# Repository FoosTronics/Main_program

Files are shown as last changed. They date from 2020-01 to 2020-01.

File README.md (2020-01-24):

# pageres

# FoosTronics
> De AI gestuurde voetbaltafel.

FoosTronics is een NLE minor project van de Hogeschool Utrecht (HU), waarbij de keeper van een fysieke voetbaltafel wordt bestuurd doormiddel van een AI. 

## Motivatie
Het project is gekozen om meer te leren over: AI, beeldherkenning, mechanica en hardware. 

## Doxygen
De Doxygen documenten zijn te vinden onder: Extra/Doxygen documentatie	

## Packages
| Package | Versie | 
| --- | --- |
| OpenCV (cv2)  | 4.1.1 | 
| TensorFlow | 1.14.1-dev20190625  | 
| numpy | 1.16.5 | 
| matplotlib | 3.1.1 | 
| Box2D | 2.3.2 | 
| smbus | 0.3.0 | 
| usb1 | 1.7.1 | 
| imutils | 0.5.3 | 
| numba | 0.45.1 | 
| pygame | 1.9.6 | 

## Hardware componenten
| Component | Versie | 
| --- | --- |
| Jetson | Nano | 
| RPI Cam | V2.1 |
| Stappenmotor 2.3 inch | KH56JM2 | 
| Stappenmotor 1.7 inch | 17PU-H502 |
| Motordriver | Arcus Technology ACE-SDE  |
| Gyroscoop | MPU6050 |

> In de handleiding staan de installatie- en gebruiksinstructies. Hierin is onder andere de opbouw van het frame te vinden onder Extra/Handleiding FoosTronics - V1.1.pdf.

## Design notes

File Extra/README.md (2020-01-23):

# FoosTronics Extra
> Extra bestanden die benodigd zijn om de FoosTronics tafel te realiseren.

## Mappen
**3D-Modellen** 
  STL files van de 3D-prints.
  
**3D-Tekeningen** 
  SLDPRT (SolidWorks) en SKP (SketchUp) files die zijn gebruikt voor het project.

**Promo**
  Promo bestanden zoals afbeeldingen en logo.
  
## Files
Handleiding voor het installeren van de FoosTronics tafel - *Handleiding FoosTronics - V1.1.pdf* 
  
## Constructie
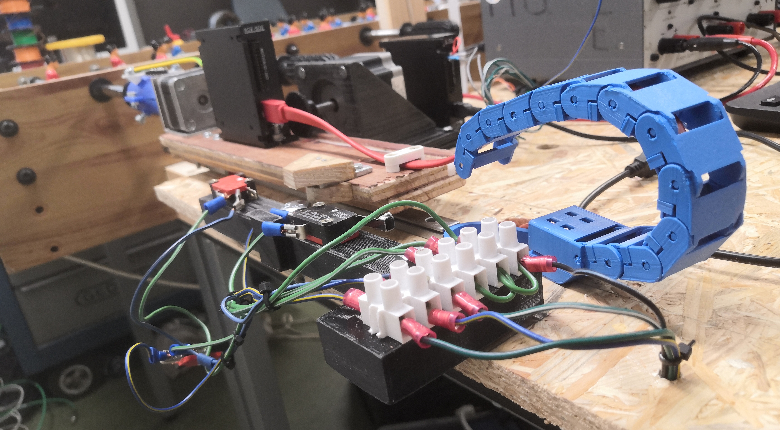
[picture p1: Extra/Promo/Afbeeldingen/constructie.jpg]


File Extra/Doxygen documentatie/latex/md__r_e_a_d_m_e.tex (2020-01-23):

C\+:\textbackslash{}\+Users\textbackslash{}kelvi\textbackslash{}\+Documents\textbackslash{}\+HU\textbackslash{}\+Next Level Engineering\textbackslash{}\+Software\textbackslash{}\+Main\+\_\+\+Foos\+Tronics\textbackslash{}\+Jetson$>$python -\/m doxypypy.\+doxypypy -\/a -\/c \char`\"{}\+C\+:/\+Users/kelvi/\+Documents/\+H\+U/\+Next Level Engineering/\+Software/\+Main\+\_\+\+Foos\+Tronics/\+Jetson/\+R\+E\+A\+D\+M\+E.\+md\char`\"{} \hypertarget{md__r_e_a_d_m_e_autotoc_md0}{}\doxysection{Foos\+Tronics}\label{md__r_e_a_d_m_e_autotoc_md0}

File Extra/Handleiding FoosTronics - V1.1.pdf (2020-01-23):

# FoosTronics

### Handleiding

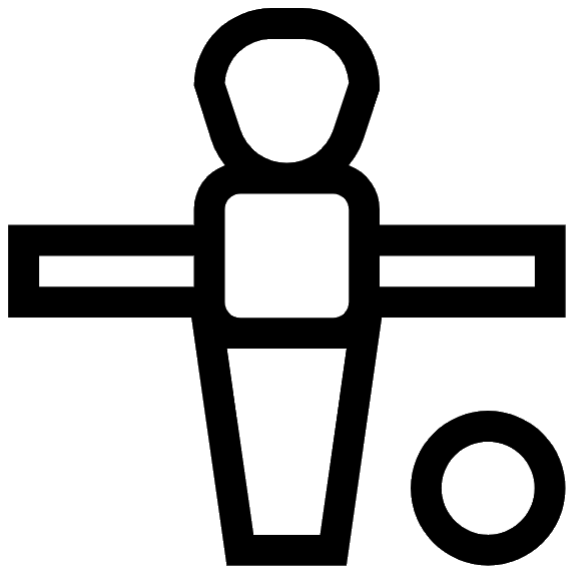
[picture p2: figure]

Namen: | Daniël Boon | 1703713
| Kelvin Sweere | 1698097
| Chileam Bohnen | 1630416
| Sipke Vellinga | 1706887
Minor: | Next Level Engineering
Cursuscode: | TIED-MNLE-18
Docent(en): | Franc van der Bent
| Abdelhak El Jazouli
| Petra Verbeek
| Michiel Scager
15-1-2019 | Versie 1.1

Pagina 2 van 51

### Revisie index

Versie | Datum | Beschrijving
V0.0 | 20-12-2019 | Opzet handleiding
V0.1 | 03-01-2020 | Inhoud toegevoegd aan de lay-out
V0.2 | 08-01-2020 | Inhoud compleet
V0.3 | 09-01-2020 | Commentaren projectgroep verbeterd
V0.4 | 09-01-2020 | Lay-out aangepast
V0.5 | 10-01-2020 | Feedback peer verwerkt
V1.0 | 10-01-2020 | Releasedatum handleiding
V1.1 | 15-01-2020 | Opmerkingen toegevoegd en verwijderd

Pagina 3 van 51

## Inhoudsopgave

Pagina 4 van 51

## 1. Inleiding

Om het project “FoosTronics”, dat is uitgevoerd tijdens de Minor Next Level Engineering van de opleiding Elektrotechniek, beter over te kunnen dragen aan andere docenten en studenten is er gekozen om een handleiding te schrijven.

Voor het gebruik van dit product worden minimaal 3e
jaars elektrotechnici verwacht. Het doel van het product is vooral om deze tijdens open dagen te laten zien.

Voor het opzetten van de handleiding is onder ander gebruik gemaakt van de lay-out van Vermeulen (Vermeulen, 2019) en voor het schriftelijke deel is gebruik gemaakt van informatie van Bloom (Bloom, 2019).

Met behulp van deze handleiding kan de FoosTronics tafelvoetbaltafel worden geïnstalleerd en in gebruik worden genomen. Er wordt vanuit gegaan dat de tafelvoetbaltafel vanaf een volledig gedemonteerd product in elkaar gezet moet worden.

In de volgende hoofdstukken zal eerst het product worden beschreven aan de hand van de kenmerken en specificaties. Vervolgens zal er worden ingegaan op welke veiligheidsvoorschriften van belang zijn om ongelukken te vermijden. Met deze kennis in het achterhoofd worden de gebruiksinstructies voorgeschreven gevolgd door de installatie instructies.
Verder zal er een troubleshooting sectie te vinden zijn waar de meeste voor te komen problemen zijn opgesomd samen met een beschrijving hoe deze zijn op te lossen. Dit wordt gevolgd door een aantal onderhoudstips om het product in een zo goed mogelijke staat te houden. De gehele handleiding wordt afgesloten met contactgegevens mochten er nog onduidelijkheden ontstaan na het lezen van deze handleiding (gaan we niet vanuit natuurlijk).

Pagina 5 van 51

## 2. Product: FoosTronics

In dit hoofdstuk worden de kenmerken en specificaties van het product beschreven.

## 2.1 Kenmerken

Het product kan het volgende:
- Met behulp van beeldherkenning wordt de tafelvoetbal bal gedetecteerd en gevolgd.
- De keeper kan met behulp van de richting van de bal bewegen naar een berekende positie.
- De keeper kan met behulp van beeldherkenning en artificiële intelligentie interactie hebben met de bal.

## 2.2 Specificaties

Jetson Nano
- Product model: NVIDIA JETSON NANO DEVELOPER KIT
- Voedingspanning: 5V
- Voedingsstroom: 4A
- Vermogen: 5-25 watt
- Maten: 69.6 mm x 45 mm
- Aansluitingen:
- Monitor: HDMI 2.0 en Displayport 1.4
- Ethernet: RJ45, M.2 Key E
- Camera connector: 1x MIPI CSI-2 DPHY lanes
- Overig: GPIO, I²C, I²
S, SPI, UART

Raspberry Pi camera
- Product Model: V2.1
- Compatibel met Raspberry Pi 4 en Jetson Nano
- Maten: 25mm x 23mm
- Aansluiting:
- Camera connector: CSI-2

Stappenmotor 2,3 inch
- Product model: KH56KM2
- Klemspanning: 12V
- Normaal stroom: 1A
- Aansluiting:
- 6-pins JST A en B-fasen

Stappenmotor 1,7 inch
- Product model: 17PU-H502
- Klemspanning: 12V
- Normaal stroom: 0,8A
- Aansluiting:
- 6-pins JST A en B-fasen

Pagina 6 van 51

Motordriver
- Arcus Technology ACE-SDE Single axis controller plus microstep driver
- Voedingsspanning: 12V – 48V
- Voedingsstroom: 3A
- Aansluitingen:
- 2-pins klemblokken voeding
- 4-pins klemblokken A en B-fasen
- USB-mini voor aansturing
- 28-pins 2mm dubbele rij IO-connector voor schakelaars

Gyroscoop
- Product model: MPU6050
- Voedingsspanning: 3.3V
- Voedingsstroom: 3.6mA
- Aansluiting:
- I

2C
- SPI

Pagina 7 van 51

## 3. BELANGRIJKE VEILIGHEIDSWAARSCHUWINGEN

## Lees dit hoofdstuk rustig door om ongelukken te voorkomen voordat u

gebruik maakt van het product.

### Productnaam: FoosTronics tafelvoetbaltafel

- Dit product maakt gebruik van spanningen en stromen die schadelijk zijn voor het menselijk lichaam, raak daarom geen blote delen aan en laat werkzaamheden aan elektronische componenten alleen over aan deskundigen.
- Controleer vooraf of alle zichtbare delen onbeschadigd zijn alvorens gebruik te maken van het product. In geval van schade, laat dit eerst repareren.
- Componenten kunnen gevoelig zijn voor statische elektriciteit. Maak bij contact daarom altijd gebruik van antistatische maatregelingen, zoals een polsband.
- Zorg ervoor dat het product in een schone en droge omgeving staat.
- Zorg ervoor dat de omgevingstemperatuur te allen tijde tussen de 15°C en 25°C is.
- Het product mag niet in direct zonlicht worden geplaatst.
- Vloeistoffen kunnen grote schade aanrichten, zorg daarom dat deze op veilige afstand van het product staan.
- Houd handen, haar, kleding en andere voorwerpen buiten bereik van tandwielen en andere bewegende delen om persoonlijk letsel te voorkomen.
- Wanneer het product niet gebruikt wordt, schakel dan eerst de Jetson Nano uit met behulp van de aan/uit knop en haal daarna de stekker uit het stopcontact.
- In geval van brand gebruik bij voorkeur een schuimbrandblusser.
- Dit product is niet geschikt voor kinderen onder de 12 jaar.
- Schakel het apparaat altijd uit alvorens er gereinigd wordt.

### Gebruik van dit product is volledig op eigen risico en er is dan ook geen enkele

aansprakelijkheid op de ontwikkelaars of andere betrokkenen.

Pagina 8 van 51

## 4. Installatie instructies

In dit hoofdstuk staat beschreven hoe de FoosTronics tafelvoetbaltafel wordt opgebouwd en geïnstalleerd. Dit hoofdstuk is voor gebruikers en doorontwikkelaars die het besturingssysteem willen installeren en de tafelvoetbaltafel willen opbouwen.

Per onderdeel van FoosTronics zijn de benodigde materialen en gereedschappen beschreven. Met behulp van een stappenplan is beschreven hoe de onderdelen gebouwd, gemonteerd en geïnstalleerd kunnen worden. Voordat wordt begonnen met de uitvoering van de installatie wordt geadviseerd eerst de stappen door te nemen.

De volgorde voor het opbouwen van FoosTronics begint bij het aansluiten en installeren van de Jetson Nano. Dit is gedaan, omdat het installeren van het besturingssysteem en benodigde Python modules veel tijd kosten. In de tussentijd van het installeren kunnen de andere onderdelen worden opgebouwd en gemonteerd.

De materialen die gebruikt worden bestaan uit halffabricaten. De technische tekeningen van deze halffabricaten staan op GitHub: https://github.com/CookieLover22/FoosTronics/tree/master/3D-prints. Wanneer blijkt dat er tijdens het uitvoeren van de installatie instructies een onderdeel mist vul deze dan a.u.b. aan, verhoog het versienummer en vermeld de wijziging in de revisie index.

Kort overzicht van de paragrafen
1. Aansluiten Jetson Nano t.b.v. installatie
2. Installeren Jetson Nano
3. Opbouwen frame
4. Monteren van de laterale mechanica
5. Monteren van de axiale mechanica
6. Monteren van Jetson Nano
7. Monteren van camera

Pagina 9 van 51

## 4.1 Aansluiten Jetson Nano t.b.v. installatie

In deze paragraaf wordt de Jetson Nano aangesloten zodat de benodigde installaties voor de Jetson Nano uitgevoerd kunnen worden. In Tabel 1 is een lijst weergegeven van alle benodigde materialen.

Tabel 1: Materialen voor het aansluiten van de Jetson Nano

Materialenlijst
Aantal | Materiaal | Afmetingen | Voorbeeld (Noun Project Inc., 2020)
1 | Jetson Nano | n.v.t
1 | 5V adapter (4A geadviseerd) | Barrel connector OD 5,5mm ID 2,1mm
1 | 5V actieve koeling met 2-pinsconnector | 40mm * 40mm * 10mm
1 | Monitor met HDMI of Display port | n.v.t
1 | HDMI of Display port kabel (aansluitbaar op de monitor) | Minimaal lengte van 1 meter
1 | M.2 wifi/bluetooth module | n.v.t.
1 | (optioneel) UTP-kabel voor internetverbinding | n.v.t.
1 | USB-keyboard | n.v.t
1 | USB-muis | n.v.t
2 | Drukknoppen
1 | Jumper cap | 2.54mm pitch

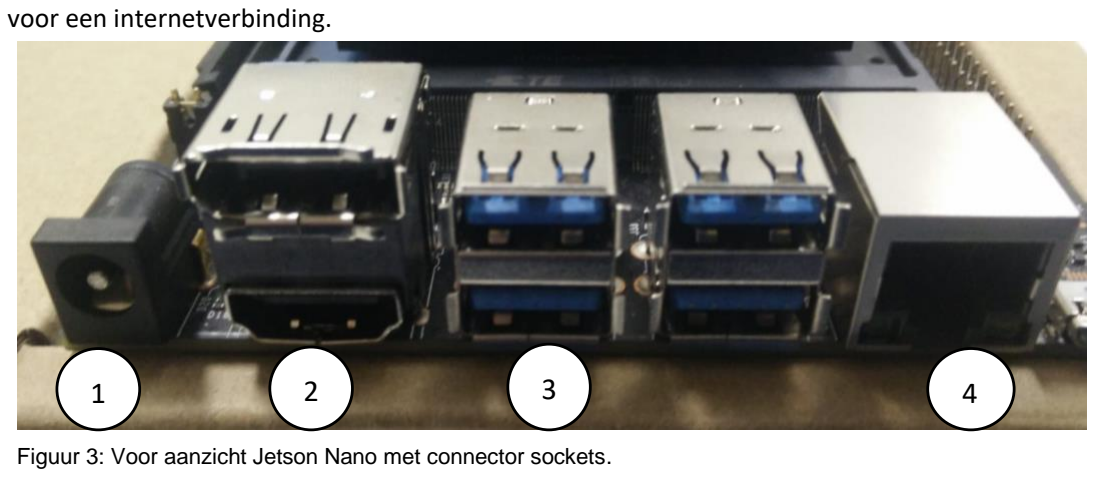
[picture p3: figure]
voor een internetverbinding.

Pagina 10 van 51

### 4.1.1 Stappenplan

1. Om een M.2 wifimodule te gebruiken, dient de Jetson Nano module van het moederbord te worden ontkoppeld. Als er geen M.2 wifimodule wordt gebruikt, ga naar stap 4.
2. In het onderstaande voorbeeld, zie Figuur 1, wordt een M.2 wifi/bluetooth module geplaatst.

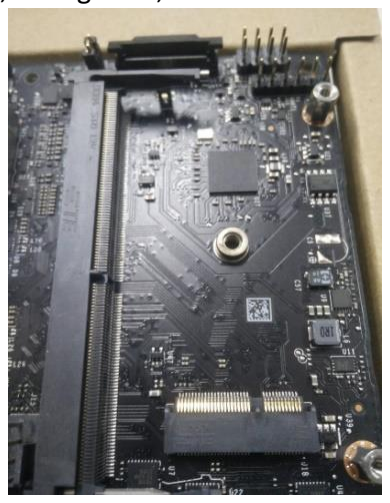
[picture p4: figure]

3. Bevestig de Jetson Nano module op het moederbord.
4. Voor het aanzetten en resetten van de Jetson Nano dienen twee knoppen en een jumper cap te worden aangesloten op header J40. Deze 8-pinsheader bevindt zich links van de CSI-2 camera connector, zie Figuur 2.
5. Bij de blauwe markering in Figuur 2 moet een jumper cap worden geplaatst. Bij de oranje markering de reset knop en bij de rode markering de power-on knop.
6. In Figuur 3 zijn de hoofdaansluitingen weergegeven van de Jetson Nano. Bij nummer 1 wordt de voedingsadapter aangesloten. Bij nummer 2 de HDMI/Display port aansluiting voor het gebruik van een monitor. Nummer 3 zijn vier USB-poorten voor het aansluiten van een muis en toetsenbord. Wanneer er geen M.2 wifimodule mogelijk is kan bij nummer 4 een UTP-kabel worden aangesloten

Figuur 1: plaatsen van M.2 wifimodule

Figuur 2: Zij aanzicht Jetson Nano met links de 8-pins header en in het midden CSI-2 camera connector.

Figuur 3: Voor aanzicht Jetson Nano met connector sockets.

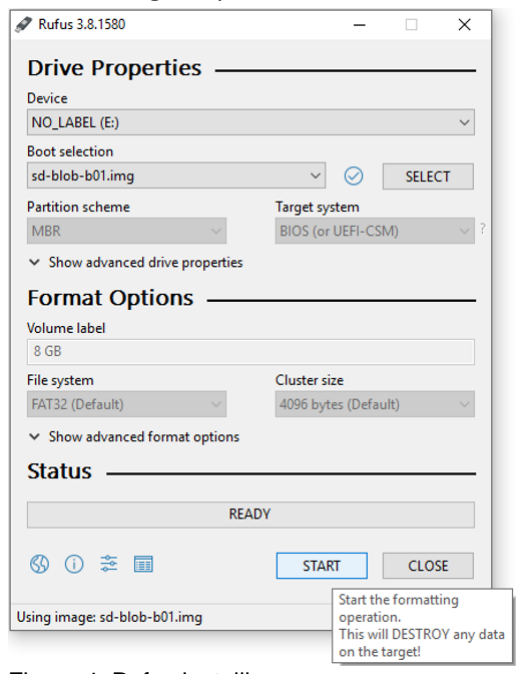
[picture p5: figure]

Pagina 11 van 51

## 4.2 Installeren Jetson Nano

Om de Jetson Nano ontwikkelbord van Nvidia te gebruiken dient een besturingssysteem en aanvullende hulpmiddelen te worden geïnstalleerd. Het besturingssysteem dat gebruikt wordt is JetPack 4.3.

De volgende stappen helpen bij het installeren van JetPack 4.3 en de aanvullende hulpmiddelen.
De benodigdheden hiervoor zijn:
- Jetson Nano
- Zie: Aansluiten Jetson Nano t.b.v. installatie op pagina 8.
- Minimaal 32 GB-micro SD-kaart klasse 10.
- Laptop/desktop met micro SD-kaart slot of een micro SD-kaart adapter.

### 4.2.1 Stappenplan

Installatie JetPack 4.3 op micro SD-kaart
1. Download de JetPack 4.3 image van Nvidia. https://developer.nvidia.com/jetson-nano-sd-card-image-r3231
2. Download Rufus 3.8 om een opstart image te schrijven naar de micro SD-kaart. https://rufus.ie/
3. Plaats de micro SD-kaart in de computer.
4. Start Rufus 3.8 executable.
5. De instellingen op de GUI moeten overeenkomen met Figuur 4.
6. Start het formatteren van de micro SD-kaart en de installatie van JetPack 4.3.
7. Sluit Rufus 3.8 en verwijder veilig de micro SD-kaart.
8. Plaats de micro SD-kaart in de Jetson Nano.
9. Sluit de overige benodigdheden aan, zie: Aansluiten Jetson Nano t.b.v. installatie op pagina 8.
10. Start de Jetson Nano op.
11. Bij de eerste keer opstarten van het OS, is er een configuratiescherm te zien. Doorloop de instructies van deze configuratie. Bij het venster met als titel “Who are you?” vul deze gegevens in:
a. Your name: | foostronics
b. Choose a password: | socbot12
(Wanneer anders gewenst, maak deze handleiding up-to-date van de nieuwe gegevens en verhoog de revisie versie.)

Figuur 4: Rufus instellingen

Pagina 12 van 51

Virtual environment aanmaken, pip install’s en library builds
1. Installeer de virtual environment applicatie door het volgende commando in de terminal in te typen en druk vervolgens op enter. Bij deze stap zal er gevraagd worden naar het wachtwoord. Vul het wachtwoord in dat is aangemaakt bij stap 11 van de installatie van JetPack 4.3.

sudo apt-get install python3-venv

2. Maak een environment met de naam “ft_env” aan door het volgende commando in de terminal uit te voeren:

sudo python3.6 -m venv ft_env

3. Activeer de environment “ft_env” met het volgende commando:

source ft_env/bin/activate

4. Installeer de benodigde librarys via pip:

sudo apt-get install pip3

sudo pip3 install usblib1

sudo pip3 install imutils

sudo pip3 install matplotlib

sudo pip3 install numba

sudo apt-get install v4l-utils

sudo pip3 install pygame

sudo pip3 install pyqt=4

sudo pip3 install pyglet

5. Bouw OpenCV V4.1.1 met de volgende commando’s: (let op dat dit bouwproces 2 tot 3 uur kan duren)

git clone https://github.com/JetsonHacksNano/buildOpenCV

cd buildOpenCV

./buildOpenCV.sh |& tee openCV_build.log

Zie voor meer informatie hierover: https://www.jetsonhacks.com/2019/11/22/opencv-4-cuda-on-jetson-nano/
6. Bouw PyBox2D met de volgende commando’s: (let op dat dit bouwproces 2 tot 3 uur kan duren)

git clone https://github.com/pybox2d/pybox2d

cd pybox2d

python3 setup.py build

python3 setup.py install

Pagina 13 van 51

7. Installeer TensorFlow 1.14 met de volgende commando’s:

sudo apt-get install libhdf5-serial-dev hdf5-tools libhdf5-dev zlib1g-dev zip libjpeg8-dev

sudo pip3 install -U numpy grpcio absl-py py-cpuinfo psutil portpicker six mock requests gast h5py astor termcolor protobuf keras-applications keras-preprocessing wrapt google-pasta

sudo pip3 install --pre --extra-index-url https://developer.download.nvidia.com/compute/redist/jp/v42 tensorflow-gpu==1.14.0+nv19.10

Zie voor meer informatie hierover: https://devtalk.nvidia.com/default/topic/1048776/jetson-nano/official-tensorflow-for-jetson-nano-/ (https://devtalk.nvidia.com/default/topic/1048776/jetson-nano/official-tensorflow-for-jetson-nano-/)

FoosTronics repository clone en test

1. Kloon de FoosTronics repository door het volgende commando in de terminal uit te voeren:

git clone https://github.com/CookieLover22/FoosTronics

2. Draai het testscript:

cd FoosTronics

python3 testscript.py

3. Wanneer de testscript print: “test geslaagd!” is de Jetson Nano gereed om gebruikt te worden voor de voetbaltafel.

Is dit echter niet het geval? Dan zal de gegeven error verholpen moeten worden, wil de Jetson Nano bruikbaar zijn voor de voetbaltafel (kijk voor mogelijk oplossingen (https://hogeschoolutrecht.sharepoint.com/sites/NLE/Gedeelde%20documenten/Technisch%20schrijven/Oudere%20versies/User%20Manual%20-%20Julain%20(tot%20blz).docx) op pagina 39).

Pagina 14 van 51

## 4.3 Opbouwen frame

In deze paragraaf wordt beschreven hoe het frame voor de tafelvoetbaltafel en componenten stapsgewijs kan worden opgebouwd. In Tabel 2 is eerst een lijst opgesomd van alle materialen en gereedschappen die hiervoor nodig zijn.

Tabel 2: Materialen- en gereedschapslijst voor het opbouwen van het frame

Materialenlijst
Aantal | Materiaal | Afmetingen | Voorbeeld (Noun Project Inc., 2020)
2 | Houten balk | 170cm x 6,9cm x 2,8cm
2 | Houten balk | 80cm x 6,9cm x 2,8cm
2 | Houten balk | 70cm x 6,9cm x 2,8cm
1 | Houten plaat | 101cm x 55cm x 1,2cm
1 | Houten plaat | 101cm x 32cm x 1,2cm
2 | Metalen hoekstrip | 76cm x 4cm x 8cm
1 | Metalen hoekstrip | 13cm x 8cm x 4cm
1 | Metalen hoekstrip | 63cm x 7,5cm x 4cm
2 | Driehoek plaat | 20,5cm x 14cm x 14cm
4 | Houten blokje | 10,5cm x 9,5cm x 7cm
19 | Zeskantbout | M8 x 80mm
2 | Zeskantbout | M8 x 25mm
21 | Zeskantmoer | M8
38 | Sluitring | M8
2 | Zeskantbout | M10 x 100mm
2 | Zeskantmoer | M10
8 | Sluitring | M10
16 | Schroef PZ-2 | 4 x 60mm
14 | Schroef PZ-2 | 4 x 25mm

Pagina 15 van 51

14 | Kraalring | M4
1 | Tafelvoetbaltafel | 1045mm x 540mm x 185mm
2 | Tafel | 80cm x 80cm x 75cm

Gereedschap

Aantal | Materiaal | Afmetingen | Voorbeeld (Noun Project Inc., 2020)
1 | Steek/ringsleutel | 13
1 | Ratelsleutel | n.v.t.
1 | Dopsleutel | 13
1 | Steek/ringsleutel | 17
1 | Schroefmachine | N.v.t.
1 | PZ-2 bit | n.v.t.
1 | Bit-verlengstuk | n.v.t.
1 | Schroevendraaier PZ-2 | n.v.t.
1 | Klauwhamer | n.v.t.
1 | Rolmaat | n.v.t.

Pagina 16 van 51

### 4.3.1 Stappenplan

Het fundament
1. Schuif de twee tafels tegen elkaar aan met de markeringen (Figuur 5) naar elkaar toe.
2. Leg de twee balken van 170cm x 6,9cm x 2,8cm over de twee tafels (aan de langste zijde). Let goed op de markeringen (Figuur 6).
3. Stop in elk gat van de balken (Figuur 7) een M8 bout met een M8 ring. Gebruik eventueel een hamer om ze er volledig in te krijgen.

Figuur 5: Markering tafels

Figuur 6: Markeringen lange balken

Figuur 7: Boutgat lange balk

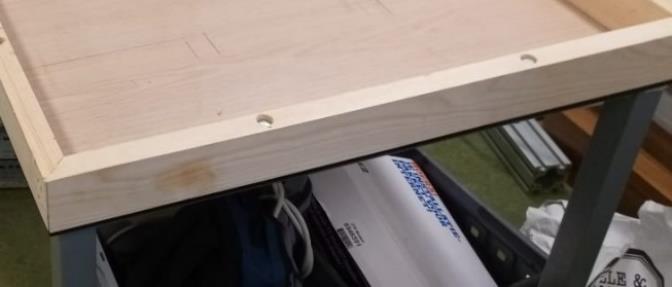
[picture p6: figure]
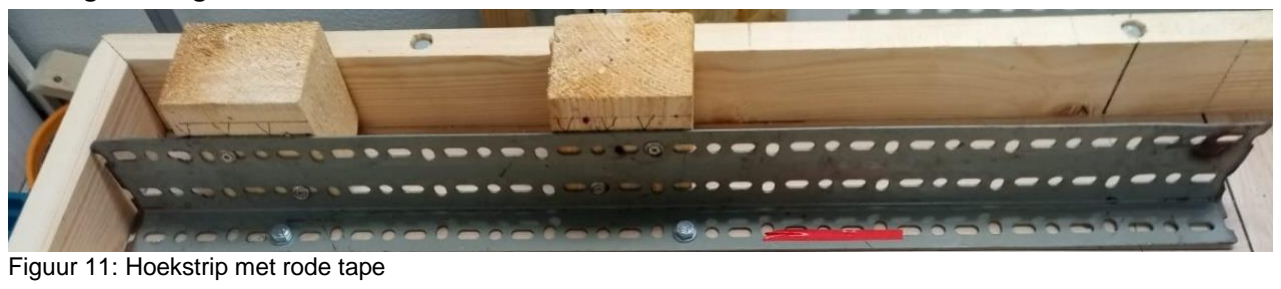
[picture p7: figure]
Figuur 11: Hoekstrip met rode tape

Pagina 17 van 51

4. Plaats aan de onderkant van de tafel op elke M8 bout een M8 ring en draai er een m8 moer op. Let op: draai deze nog niet helemaal vast. Dan kun je het geheel bijstellen.
5. Pak de twee balken van 80cm x 6,9cm x 2,8cm en plaats deze tegen de uiteinden van de lange balken met de markeringen zoals in Figuur 8.
6. Stop in elk gat van de twee balken (Figuur 9) een M8 bout met een M8 ring. Gebruik eventueel een hamer om ze er volledig in te krijgen.
7. Plaats aan de onderkant van de tafel op elke M8 bout een M8 ring en draai er een M8 moer op. Let op: draai deze nog niet helemaal vast. Dan kun je het geheel bijstellen.
8. Draai nu in alle hoeken twee 4 x 25mm schroeven (Figuur 10). Gebruik hiervoor een schroefmachine met een verlengstuk en een PZ-2 bit.
9. Draai nu alle M8 moeren in de balken goed vast en zorg dat het geheel zo recht en haaks mogelijk staat.

Opstelling
10. Pak nu de twee hoekstrippen van 76cm x 4cm x 8cm. Leg de strip met de rode tape aan de kant waar de tekst “Rood” staat (Figuur 11). Plaats de strip zo dat de hoge kant van de strip in het verlengde van de lange balk ligt.

Figuur 8: Plaatsing en markering korte balk

Figuur 9: Boutgaten korte balk

Figuur 10: Balk verbindingsgaten

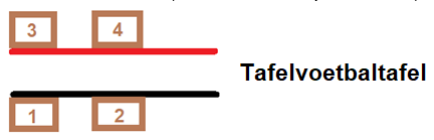
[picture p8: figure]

Pagina 18 van 51

11. Monteer nu, op de plekken waar de gaten door de tafel zijn geboord, M8 bouten met een ring en aan de onderkant van de tafel M8 moeren met een ring. Twee per strip, zie Figuur 11.
12. Pak nu de blokjes van 10,5cm x 9,5cm x 7cm. Leg ze op de volgorde zoals weergegeven in Figuur 12, tussen de metalen hoekstrip en de balk. De rode lijn is de hoekstrip met de rode tape.
13. Positioneer de blokjes tussen de markeringen en op de hoogte van de pijlen, zoals weergegeven in Figuur 13.

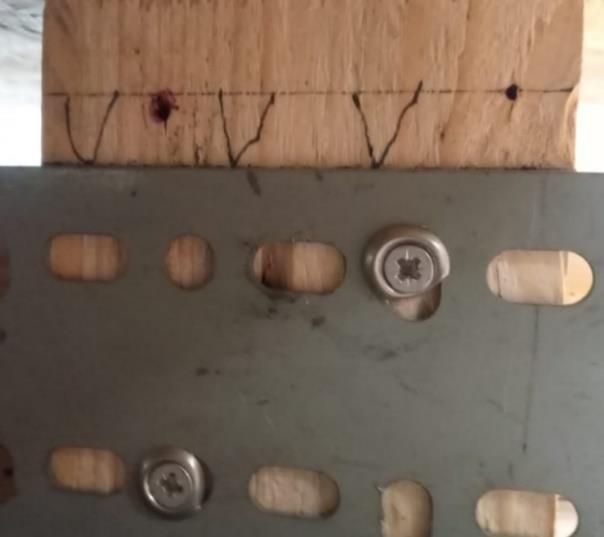
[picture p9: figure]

14. Schroef de blokjes vervolgens vast. Gebruik hiervoor per blokje twee 4 x 60mm schroeven samen met M4 kraalringen, de schroefmachine, een verlengstuk en een PZ-2 bit.

Camera statief
15. Pak nu de tafelvoetbaltafel en de balk van 103cm x 6,9cm x 2,8cm. Monteer de balk aan de tafelvoetbaltafel met behulp van twee M8 bouten en twee M8 ringen met aan de andere kant twee M8 moeren met twee M8 ringen in de voorgeboorde gaten (Figuur 14).
16. Monteer de hoekstrip van 13cm x 8cm x 4cm onderaan de balk (Figuur 14) van 103cm x 6,9cm x 2,8cm. Gebruik hiervoor de 4 x 25mm schroeven samen met een M4 kraalring.

Figuur 12: Plaatsing houten blokjes

Figuur 13: Positionering houten blokjes

Figuur 14: Monteren camera statief aan tafel

Pagina 19 van 51

17. Leg de tafelvoetbaltafel in de lengte over de breedte van de balken. Let erop dat, vanuit de blauw spelers gezien, de rechterkant het korte stuk van de tafel is, zie Figuur 15. De tafelvoetbaltafel moet binnen de lijnen liggen.
18. Pak nu de twee balken van 70cm x 6,9cm x 2,8cm en schuif deze onder de nog twee open sleuven door van de tafelvoetbaltafel, zie Figuur 15. Let erop dat de nummeringen overeenkomen (1-4). Bij 3 en 4 moeten de schroefgaten naar boven. De balken moeten binnen de lijnen komen, aan beide kanten van de tafelvoetbaltafel op ongeveer dezelfde afstand.
19. Bevestig de hoekstrip van 13cm x 8cm x 4cm aan de tafel in de voorgeboorde gaten (Figuur 16). Gebruik hiervoor de M8 x 25mm bouten samen met M8 ringen en draai deze aan de onderkant vast met M8 ringen en moeren.

Opstelling mechanica
20. Leg de plaat van 101cm x 55cm x 1,2cm over de blokjes, met de pijl naar boven richting de tafelvoetbaltafel. Stem de markeringen aan de onderkant af met de blokjes. Schroef de plaat vast met de 4 x 60mm schroeven in de voorgeboorde gaten. Gebruik hiervoor de schroefmachine, het verlengstuk en de PZ-2 bit. Zie Figuur 17 voor een voorbeeld.

Figuur 16: Boutgaten camerastatief en tafel

Figuur 17: Grote houten plaat gemonteerd op houten blokjes

Figuur 15: Tafelvoetbaltafel met camerastatief

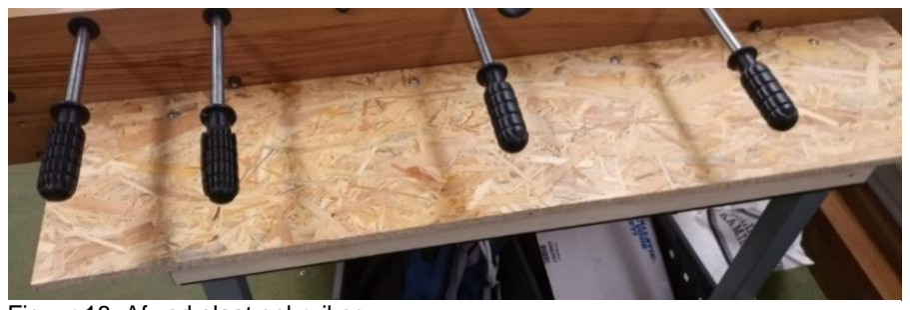
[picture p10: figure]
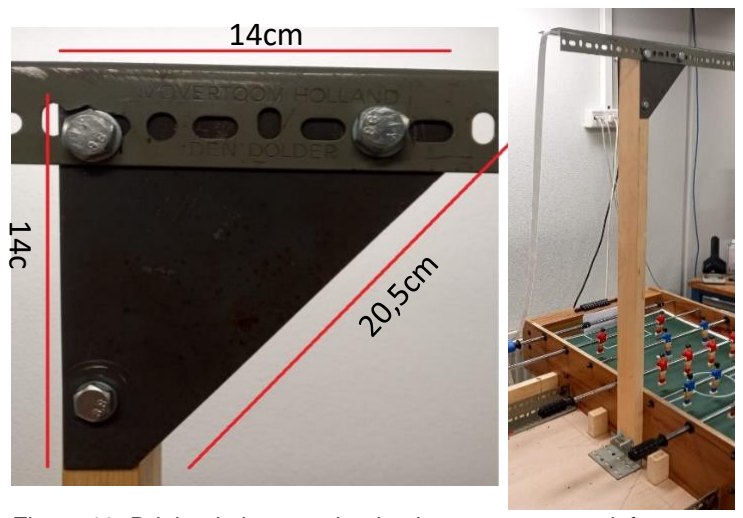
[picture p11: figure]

Pagina 20 van 51

Afwerking gebruiker
21. Leg de plaat van 101cm x 32cm x 1,2cm aan het andere uiteinde met de schroefgaten naar de tafel toe. Zorg dat de markeringen aan de onderkant zitten en goed liggen met de balkconstructie. Schroef de plaat vast met de 4 x 25mm schroeven in de voorgeboorde gaten met M4 kraalringen. Gebruik hiervoor de schroefmachine, het verlengstuk en de PZ-2 bit. Zie Figuur 18 voor een voorbeeld.

Camera statief
22. Voor deze stap zijn de twee driehoek platen nodig van 20,5cm x 14cm x 14cm.
Plaats aan elke zijde aan de bovenkant van de balk van 103cm x 6,9cm x 2,8cm deze twee driehoek platen, zie Figuur 19. Gebruik hiervoor eerst één M8 x 80mm bout met een ring en duw deze door het onderste gat, om de platen op hun plek te houden.
23. Pak nu de hoekstrip van 63cm x 7,5cm x 4cm erbij. Deze komt op de bovenkant rechts, gezien vanuit de balk richting de tafelvoetbaltafel. Het afwijkende gat van de hoekstrip komt bij het gat linksboven van de driehoek plaat zie Figuur 19. Bevestig de hoekstrip aan de twee driehoek platen met M10 x 100mm bouten, samen met M10 ringen en M10 moeren.

Figuur 19: Driehoekplaten en hoekstrip aan camerastatief

Figuur 18: Afwerkplaat gebruiker

m

Pagina 21 van 51

## 4.4 Monteren van de laterale mechanica

In deze paragraaf wordt beschreven hoe de mechanica voor de laterale beweging stapsgewijs kan worden gemonteerd. In Tabel 3 is een lijst te zien van alle materialen en gereedschappen die hiervoor nodig zijn.

Tabel 3 Materialen- en gereedschapslijst laterale beweging.

Materialenlijst
Aantal | Materiaal | Afmetingen | Voorbeeld (Noun Project Inc., 2020)
1 | Eindschakelaarsbord | n.v.t. | Zie nummer 1 in Figuur 20
1 | Tandheugelplatform | n.v.t. | Zie nummer 2 in Figuur 20
1 | Stappenmotorhouder | n.v.t. | Zie nummer 3 in Figuur 20
1 | Motordriver | N.v.t.
1 | Stappenmotor | KH56KM2
4 | PZ-2 schroeven | 4 x 25 mm
4 | Sluitringen | M4
2 | Platkopbouten | M4 x 10 mm
2 | Kruiskopbouten | M3 x 4 mm
1 | Stappenmotorconnector | JTS 6-pins stappenmotorconnector naar 4-pins fasen connectoren voor de motor.

Gereedschapslijst
Aantal | Materiaal | Afmetingen | Voorbeeld (Noun Project Inc., 2020)
1 | PZ-2 | N.v.t.
1 | Steek/ringsleutel | 7
1 | Platkopschroevendraaier
1 | Punttang | n.v.t.

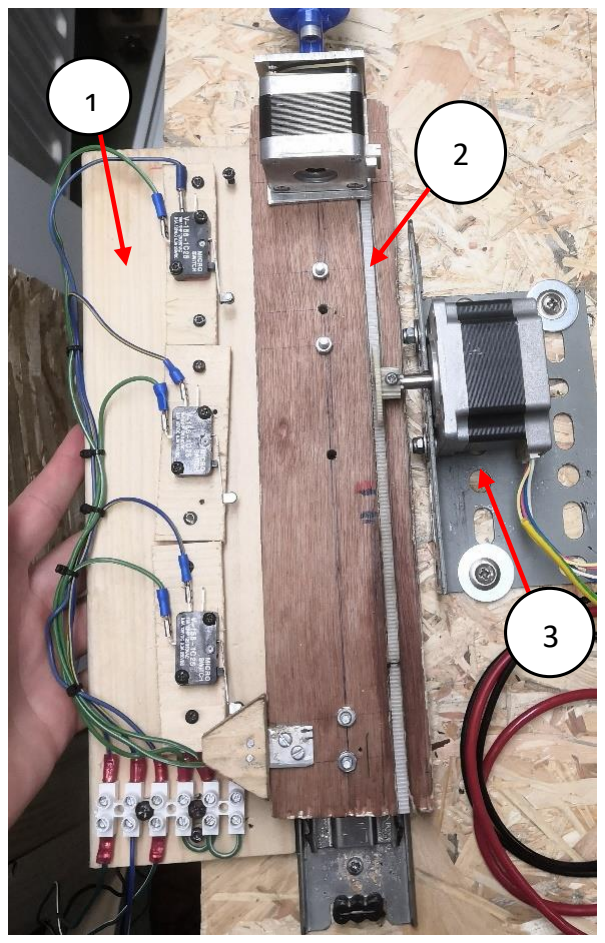
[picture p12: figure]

Pagina 22 van 51

In Figuur 20 is het uiteindelijk resultaat te zien van dit stappenplan.

Figuur 20 Laterale beweging opgedeeld in onderdelen.

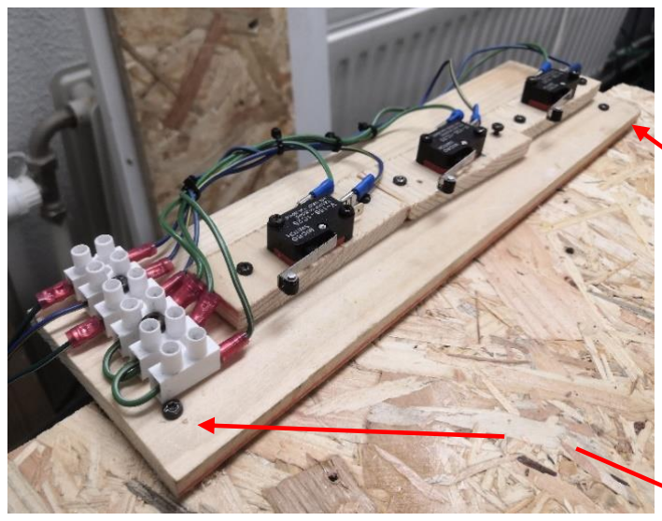
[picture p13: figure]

Pagina 23 van 51

### 4.4.1 Stappenplan

Eindschakelaarsbord
1. Plaats het eindschakelaarsbord zoals is weergegeven in Figuur 21. Zorg hierbij dat de twee gaten (die zijn gemarkeerd met de rode pijlen) zijn uitgelijnd. Let hierbij op de markeringen die op de tafel staan genoteerd.
2. Schroef de kruiskopschroeven vast met de schroevendraaier.

Tandheugelplatform

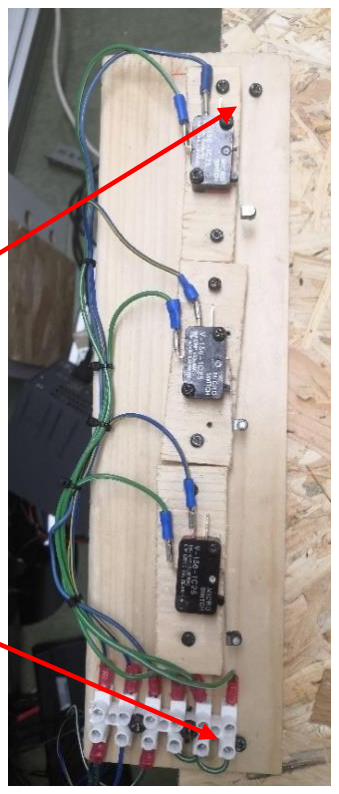
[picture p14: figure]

3. Plaats de ladegeleider met tandheugel tegen het eindschakelaarsbord, zoals is afgebeeld in Figuur 22. Zorg hierbij dat de gaten in de ladegeleider zijn uitgelijnd met de voorgeboorde gaten. Dit is weergegeven met de rode pijlen.
4. Schroef twee kruiskopschroeven van 25 mm in de gaten. De tandheugel en de ladegeleider zijn nu aan de tafel bevestigd.

Motorhouder en motor
5. Schroef aan beide kanten doormiddel van een kruiskopschroevendraaier de M3 schroeven op de tandwieloverbrenging van de stappenmotor.
6. Plaats M4 x 10 mm kruiskopbouten met drie ringetjes door de stappenmotor.

Figuur 21 Opbouw eindschakelaarsbord. Hierbij is links een schuin vooraanzicht en rechts een bovenaanzicht.

Figuur 22 Uitlijnen van de ladegeleider.

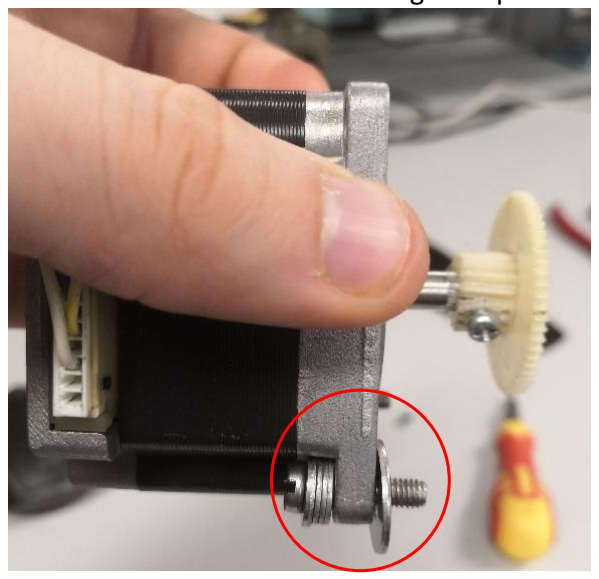
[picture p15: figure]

Pagina 24 van 51

7. Plaats daarna een carrosseriering M4 op de bouten, zoals is weergegeven in Figuur 23.
8. Plaats twee keer de M4 x 10 mm kruiskopbout door de stappenmotor. Dit staat weergegeven in Figuur 24 met het getal ‘1’.
9. Monteer aan beide kanten een carrosseriering en een M4 moer op de uit stekende bouten. Dit staat weergegeven in Figuur 24 bij getal ‘2’. Houdt met de steeksleutel de moeren vast, terwijl met een platkopschroevendraaier de bouten worden aangedraaid.
10. Zet de stappenmotor op de houder zoals bij nummer ‘1’ is afgebeeld in Figuur 24.
11. Plaats nu op beide bouten een M4 carrosseriering en een M4 (borg)moer, zoals bij nummer ‘2’ staat afgebeeld in Figuur 24.
12. Houdt met de steeksleutel de moeren vast en draai met de platbekschroevendraaier de bouten vast.

Figuur 23 Opbouw boutverbinding stappenmotor

Figuur 24 Monteren stappenmotor op houder.

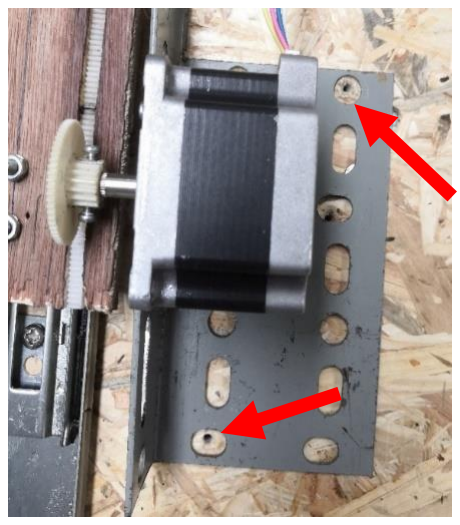
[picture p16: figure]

Pagina 25 van 51

13. Lijn de stappenmotor met houder uit, doormiddel van de gaten naast de tandheugel. Dit staat weergegeven in Figuur 25 met de rode pijlen.
Bevestig PZ-2 4*25 mm schroeven met M4 kraalringen doormiddel van een kruiskopschroevendraaier. LET OP: voordat de schroeven vast zitten, moet gecontroleerd worden of het tandwiel recht over de tandheugel kan lopen.

Stappenmotordriver
14. Schuif de stappenmotordriver op de omcirkelde bout, zoals is weergegeven in Figuur 26. Zorg ervoor dat de mini usb-poort naar de richting van de pijl wijst. In Figuur 26 is met de pijl de schuifrichting weergegeven.
15. Lijn de stappenmotor uit met het voorgeboorde gat aan de tafelzijde. Dit is aangegeven in Figuur 27 met de rode cirkel.

Figuur 26 Schuifrichting stappenmotordriver.

Figuur 25: Positionering van de houder op de tandheugel.

Figuur 27: Uitlijning stappenmotordriver.

Pagina 26 van 51

16. Bevestig aan de onderkant van het tandheugelplatform een M4 platkopbout, die de stappenmotordrive bevestigd op het platform van de tandheugel.
17. Bevestig op de uitstekende bout een M4 veerring en M4 moer.
18. Houdt met de punttang de moer vast, terwijl de bout aan de onderkant wordt aangedraaid doormiddel van een platbekschroevendraaier. LET OP: doordat de ruimte tussen de moer en de stappenmotordriver klein is, past een (combinatie)tang niet.
19. Bevestig nu vanaf de zes- pins JST A- en B-fasen connector van de stappenmotor een kabel naar de vier pins klemblokken (A en B-fasen) van de driver.

Pagina 27 van 51

## 4.5 Monteren van de axiale mechanica

In deze paragraaf wordt beschreven hoe de mechanica voor de axiale beweging stapsgewijs kan worden gemonteerd. Als eerste zullen alle materialen en gereedschappen opgesomd staan, zie Tabel 4. Daarna zullen de stappen van de axiale mechanica stapsgewijs worden uitgelegd.

Tabel 4 Materiaal- en gereedschapslijst axiale beweging.

Materialenlijst
Aantal | Materiaal | Afmetingen | Voorbeeld (Noun Project Inc., 2020)
2 | Hendelklem | N.v.t.
1 | Gyroscoop | N.v.t.
1 | Verbindingsstuk | N.v.t.
1 | Stappenmotorhouder | N.v.t.
1 | Stappenmotor | 17PU-502 (1,7 inch)
2 | PH-2 schroef | M2 x 3mm
2 | Zeskantsbout met zaagsnede | M3 x 10 mm
6 | Inbusbout | M4 x 8 mm
2 | Inbusbout | M4 x 5 mm
4 | Inbusbout | M4 x 4 mm
2 | Verzonken inbusbout | M4 x 27 mm
2 | Inbusbout | M5 x 10 mm
4 | Zeskantmoer | M4
4 | Verzonkenhoutschroef | 4 x 25 mm

Gereedschapslijst
Aantal | Materiaal | Afmetingen | Voorbeeld (Noun Project Inc., 2020)
1 | Steek/ringsleutel | 7
1 | Steek/ringsleutel | 11

Pagina 28 van 51

1 | Kruiskopschroevendraaier | M2
1 | Platkopschroevendraaier | M3
1 | PZ-2 schroevendraaier | M4
1 | Punttang | n.v.t

### 4.5.1 Stappenplan

Hendelmal
1. Zet de twee hendelklemmen op de hendel van de keeper die wordt geautomatiseerd, zoals is weergegeven in Figuur 28.
2. Zorg tijdens het klemmen dat de inbusschroeven M4 x 8mm in beide hendelklemmen gaan, zoals is weergegeven in Figuur 29.

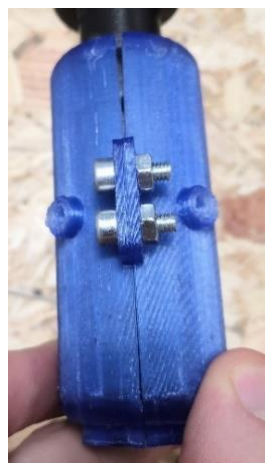
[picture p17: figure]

3. Monteer nu de moeren aan de onderkant van de hendel klemmen. Zorg ervoor dat de moeren hand vast worden gemonteerd. De kans op breken van het materiaal is namelijk groot. Als dit is gelukt, kunnen de hendel klemmen worden losgelaten.
4. Monteer twee M4 x 5 mm inbusschroeven aan de onderkant van de hendel klem doormiddel van een inbussleutel.

Figuur 29 Links voorzijde van gemonteerde hendel klemmen en rechts zijaanzicht.

Figuur 28: Klempositie hendel klemmen.

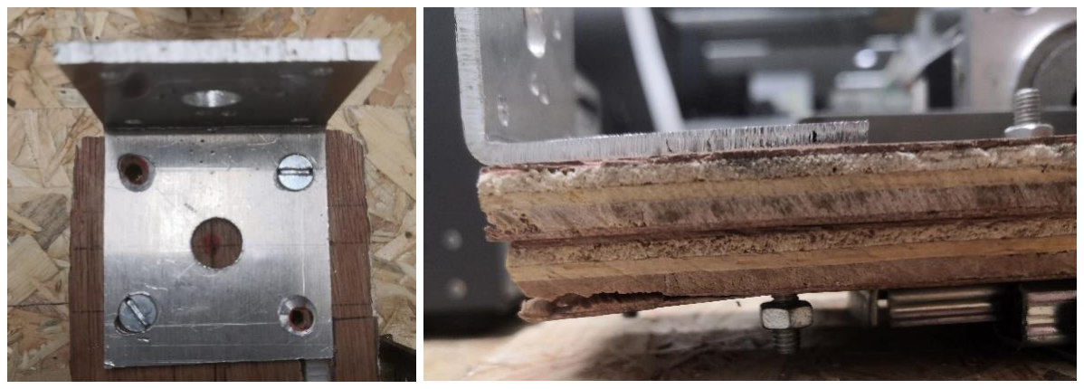
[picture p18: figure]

Pagina 29 van 51

4. Positioneer de gyroscoophouder zoals is afgebeeld in Figuur 30. Monteer daarna de M4 x 8 mm schroeven met een kruiskop.

Verbindingsstuk
5. Plaats het verbindingsstuk zoals weergegeven is in Figuur 31 en monteer de M5 x 10 mm bouten doormiddel van een M5 inbussleutel.

Houder
6. Plaats de stappenmotorhouder zoals is afgebeeld in de linker foto in Figuur 32 met de M4 x 27 mm bouten.
7. Positioneer twee M4 moeren onder de constructie doormiddel van een punttang. Bevestig nu de bouten met een platkopschroevendraaier.

Figuur 32 Bovenaanzicht en zijaanzicht motorhouder.

Figuur 30 Klemrichting hendel klemmen.

Figuur 31 Gemonteerde verbindingsstuk.

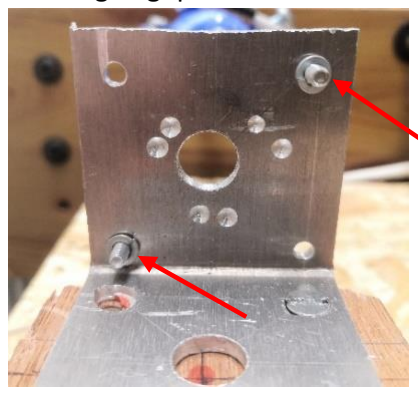
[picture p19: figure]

Pagina 30 van 51

8. Bevestigd de M3 bouten door de stappenmotorhouder zoals is weergegeven in Figuur 33. In dit figuur staan twee pijlen die wijzen naar de schroeven. Bij de schroefverbinding wordt bij beide zijdes twee veerringen geplaatst.
9. Monteer de stappenmotor op de schroeven doormiddel van een M3 platbekschroevendraaier.
10. Plaats de stappenmotor as in het verbindingsstuk, zoals weergegeven is in Figuur 34.
11. Monteer de M2 x 3 mm kruiskopschroeven op het verbindingsstuk (zie Figuur 35) doormiddel van de bijbehorende M2 handschroevendraaier. LET OP: zorg dat dit met een handschroevendraaier gebeurt en niet met een schroefmachine.
12. Test nu de axiale M2 bevestiging door de stappenmotor lateraal en axiaal te bewegen. Wanneer deze blijft zitten is de axiale beweging in zijn geheel gerealiseerd.

Figuur 33 stappenmotorhouder met bouten.

Figuur 34 Richting van de bevestiging van de as.

Figuur 35 M2 axiaal borging van het verbindingsstuk.

Pagina 31 van 51

## 4.6 Monteren Jetson Nano

In deze paragraaf wordt beschreven hoe de Jetson Nano stapsgewijs kan worden gemonteerd. In Tabel 5 is een lijst van alle materialen en gereedschappen te zien die hiervoor nodig zijn.

Tabel 5: Materialen- en gereedschapslijst monteren Jetson Nano

Materialenlijst
Aantal | Materiaal | Afmetingen | Voorbeeld (Noun Project Inc., 2020)
4 | Zeskantbout | M8 * 30mm
4 | Zeskantmoer | M8
8 | Sluitring | M8
1 | Houten plaat | 140mm * 80mm * 3mm
8 | Inbusbout | M2.5 * 10mm
4 | Zeskantmoer | M2.5
4 | Kunststof ring | M2.5
4 | Kunststof afstandsbus | M2.5 * 10mm
1 | Jetson Nano | n.v.t.

Gereedschap

Aantal | Materiaal | Afmetingen | Voorbeeld (Noun Project Inc., 2020)
1 | Steek/ringsleutel | 13
1 | Steek/ringsleutel | 5
1 | Inbussleutel | 2.7

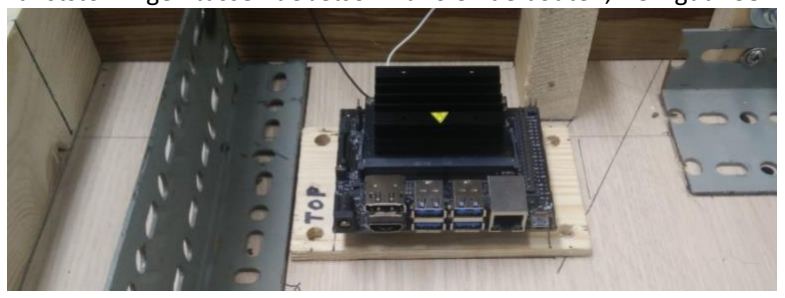
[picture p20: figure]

Pagina 32 van 51

### 4.6.1 Stappenplan

1. Verzamel de materialen uit de materialenlijst en het nodige gereedschap.
2. Bevestig eerst vier afstandsbussen aan de bovenzijde van de houten plaat, dit is gemarkeerd met Jetson Nano, zie Figuur 36. En zet ze vast m.b.v. vier M2.5 inbusbouten.

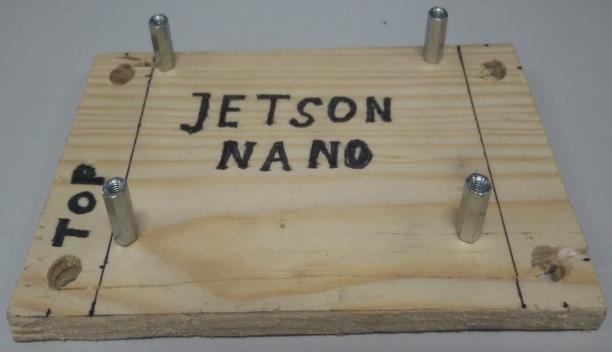
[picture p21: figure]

3. Bevestig de houten plaat op de gemarkeerde plaats op het tafelblad, zie Figuur 37. Gebruik hiervoor de M8 bouten, moeren en ringen.
4. Bevestig de Jetson Nano aan de afstandsbussen m.b.v. vier M2.5 inbusbouten. Gebruik de vier kunststof ringen tussen de Jetson Nano en de bouten, zie Figuur 38.

Figuur 36: Houten plaat met Jetson Nano markering

Figuur 37: Houten plaat bevestigd op de tafel.

Figuur 38: Eindresultaat montage Jetson Nano

Pagina 33 van 51

## 4.7 Monteren camera

In deze paragraaf wordt beschreven hoe de camera stapsgewijs kan worden gemonteerd. Hierbij wordt aangenomen dat de instructies voor het installeren van de Jetson Nano (zie pagina 11), het opbouwen van het frame (zie pagina 14) en het monteren van de Jetson Nano (zie pagina 31) succesvol zijn uitgevoerd. Tijdens het uitvoeren van de volgende instructies dient rekening te worden gehouden met de veiligheidswaarschuwingen (zie pagina 7). In Tabel 6 is een lijst gemaakt van de benodigdheden.

Bij de volgende situaties kan er bij een andere stap van het stappenplan begonnen worden:
- Is de camera in behuizing al gerealiseerd, maar staat deze los van het frame? Dan kan er bij stap 4 worden begonnen.
- Is de camera in behuizing al gemaakt en zit deze op het frame, maar zit deze los? Dan kan er bij stap 6 worden begonnen.
- Is de camera in behuizing al gemaakt en zit deze vast op het frame, maar de camera positie moet opnieuw gekalibreerd worden? Maak de moeren gedeeltelijk los zodat de camera vrij bewogen kan worden en dan kan er bij stap 6 worden begonnen.

Tabel 6 Materialen- en gereedschapslijst monteren camera

Materialenlijst
Aantal | Materiaal | Afmetingen | Voorbeeld (Noun Project Inc., 2020)
1 | Voetbaltafel opstelling (met frame en Jetson Nano erop gemonteerd) | n.v.t
1 | 5V adapter (4A geadviseerd) | Barrel connector OD 5,5mm ID 2,1mm
1 | Monitor met HDMI of Display port | n.v.t
1 | HDMI of Display port kabel (aansluitbaar op de monitor) | Minimaal lengte van 1 meter
1 | USB-keyboard | n.v.t
1 | USB muis | n.v.t
1 | Raspberry Pi camera (Raspicam V2.1) | n.v.t
1 | 0.67X wide angle lens | 15mm diameter
1 | Bovenstuk camera behuizing | n.v.t

Pagina 34 van 51

1 | Onderstuk camera behuizing | n.v.t
1 | CSI-2 ribbon kabel | Minimale lengte van 1,5 meter
4 | Inbusbout | M3 * 30mm
4 | Zeskantmoer | M3
2 | Zeskantbout | M8 *80mm
2 | Zeskantmoer | M8
1 | Houten plaat voor verbinding camera met het frame. | Zie Bijlage 2 op pagina 51

Gereedschapslijst
Aantal | Materiaal | Afmetingen | Voorbeeld (Noun Project Inc., 2020)
1 | Inbussleutel | 3
1 | Steeksleutel | 5.5

### 4.7.1 Stappenplan

1. Sluit de ribbon kabel aan op de Raspberry pi camera. Zorg hierbij dat de contactpuntjes richting het PCB zijn bij het aansluiten.
2. Zet de Rasberry pi camera op het onderstuk van de behuizing en zet het bovenstuk op de camera en onderstuk. Als er een “klik” te horen is, is deze juist in elkaar gezet.
3. Draai de lens op het bovenstuk van de behuizing. Het resultaat is vergelijkbaar met Figuur 39.
4. Monteer de behuizing met camera aan de houten plaat met de vier M3 inbusbouten en moeren.

Figuur 39: Camera in behuizing gemaakt

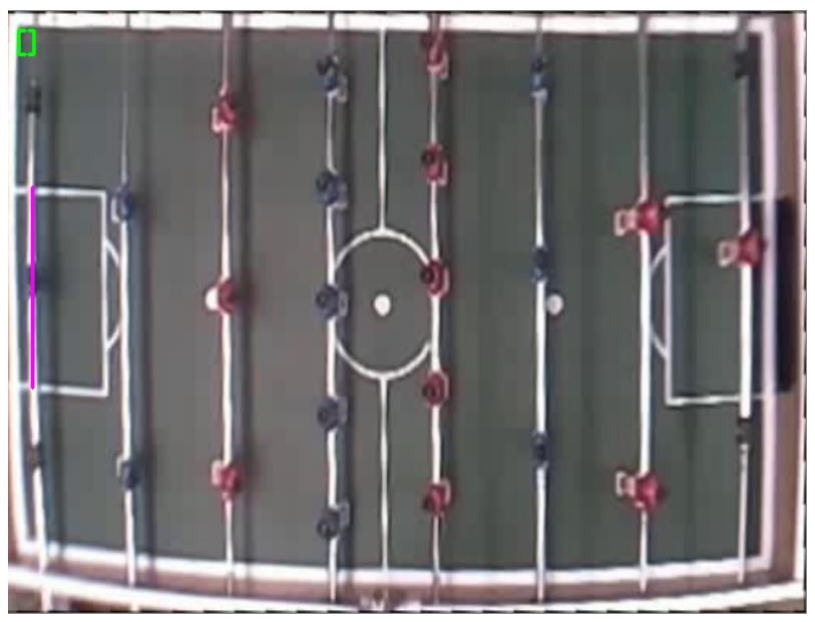
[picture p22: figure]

Pagina 35 van 51

5. Monteer de houten plaat met behuizing met behulp van de M8 bouten, moeren, steeksleutel en inbussleutel aan het frame en zet de ribbon kabel languit over het frame. Het resultaat is vergelijkbaar met Figuur 40. Maak hierbij de moeren nog niet vast zodat de camera nog vrij bewogen kan worden.

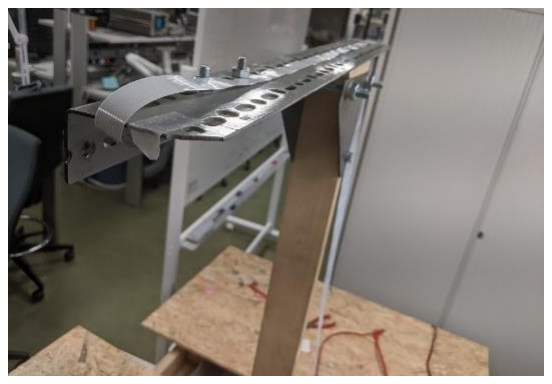
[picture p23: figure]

6. Sluit het keyboard, muis, monitor en ribbon kabel aan op de Jetson Nano (als dit nog niet gedaan is).
7. Sluit de 5V adapter aan op de Jetson Nano.
8. Wanneer alles goed is aangesloten toont de monitor dat de Jetson Nano aan het opstarten is.
9. Login op de Jetson Nano met het wachtwoord: “socbot12”
10. Open de terminal en voer de commando’s uit:

source ft_env/bin/activate

cd FoosTronics

11. Voer het volgende commando uit om de camera positie te kalibreren:

python3 kalibratie_camera_positie

12. Op de monitor verschijnt er een venster met het camerabeeld en een paars gekleurde lijn vergelijkbaar met Figuur 41. Verschuif de camera zo op het frame, dat de stang van de keeper evenwijdig is en de paarse lijn erboven staat. Als het beeld hieraan voldoet, monteer de M8 moeren vast aan het frame met steeksleutel en inbussleutel.
13. Als alle bovenstaande stappen zijn voltooid, is de kalibratie geslaagd en is de camera gereed voor gebruik.
Druk op ‘q’ om het Python programma af te sluiten.

Figuur 40: Links onderaanzicht, rechts bovenaanzicht van de camera aan het frame

Figuur 41: Voorbeeldvenster van juist gekalibreerde camera positie.

Pagina 36 van 51

## 5 Gebruikersinstructies

In dit hoofdstuk worden instructies gegeven over hoe de tafelvoetbaltafel in gebruik kan worden genomen. In Tabel 7 zijn alle benodigde materialen weergegeven voor het uitvoeren van de gebruikersinstructies.

Tabel 7 Materialenlijst gebruikersinstructies

Materialenlijst
Aantal | Materiaal | Afmetingen | Voorbeeld (Noun Project Inc., 2020)
1 | Voetbaltafel opstelling (met mechanica, frame, stappenmotordrivers, Jetson Nano en camera erop aangesloten) | n.v.t
1 | 5V adapter (4A geadviseerd) | Barrel connector OD 5,5mm ID 2,1mm
1 | Monitor met HDMI of Display port | n.v.t
1 | HDMI of Display port kabel (aansluitbaar op de monitor) | Minimaal lengte van 1 meter
1 | USB-keyboard | n.v.t
1 | USB muis | n.v.t
2 | 12V/1A voeding (en benodigde voedingsbekabeling voor de motordrivers) | n.v.t
2 | USB-mini kabels | n.v.t

Pagina 37 van 51

## 5.1 Stappenplan

1. Sluit het keyboard, muis en monitor aan op de Jetson Nano.
2. Sluit de twee stappenmotordrivers aan op de twee stappenmotoren.
3. Sluit de twee stappenmotordrivers via de USB-mini kabels aan op de Jetson Nano.
4. Sluit de 5V adapter aan op de Jetson Nano.
5. Wanneer alles goed is aangesloten, toont de monitor dat de Jetson Nano aan het opstarten is.
6. Login op de Jetson Nano met het wachtwoord: “socbot12”.
7. Open de terminal op de Jetson Nano en voer de volgende commando’s uit:

source ft_env/bin/activate

cd FoosTronics

8. Sluit de 12V aan op de twee stappenmotordrivers.
9. Om het programma met getrainde artificiële intelligentie af te draaien, voer het volgende commando uit:

Python3 ImageProcessingAI.py

10. Wanneer de code door de initialisatie heen is (dit duurt ongeveer 10 seconden), is de tafelvoetbaltafel klaar voor gebruik.

Druk op ‘q’ om het Python programma af te sluiten als dat gewenst is.

## 5.2 Spelbeschrijving

FoosTronics is een tafelvoetbaltafel waarbij de keeper wordt aangestuurd door een zelflerend systeem. Dit zelflerend systeem is getraind met behulp reinforcement learning. De uitdaging bij dit spel is om te scoren met de spitsen.

Bij het opstarten van de applicatie moet eerst het speelveld worden geselecteerd. Dit wordt gedaan m.b.v. slide bars. Figuur 42 laat deze slide bars zien. Voor het selecteren van het speelveld moeten de rode randen de witte buitenlijnen omtrekken. Vervolgens moet de kleur van de bal worden gekalibreerd. Dit wordt gedaan door de bal op het tafelvoetbalveld te leggen. Het kalibreren van de balkleur is gelukt wanneer alleen de kleur van de bal zichtbaar is op het pop-up venster.

Figuur 42: Selecteren speelveld en kalibreren balkleur

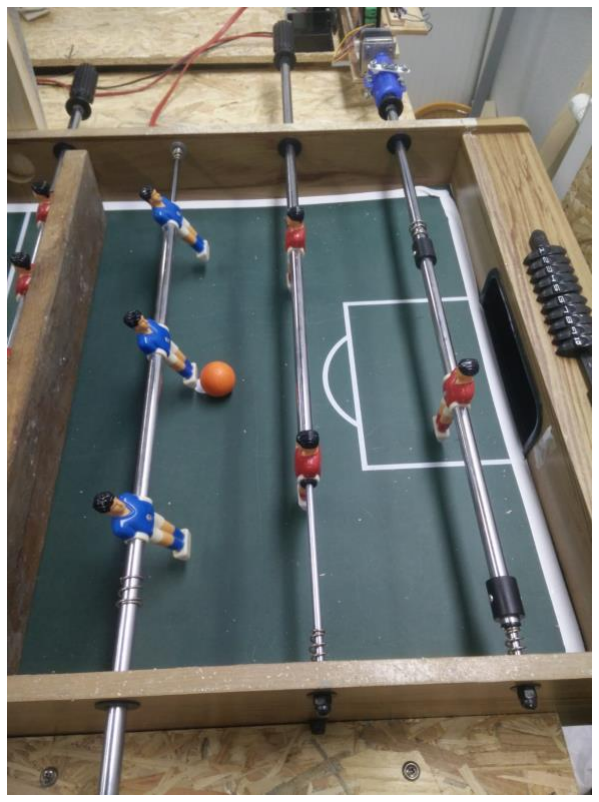
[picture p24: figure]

Pagina 38 van 51

Na het instellen van de balkleur en speelveld kan het spel gestart worden. In tegenstelling tot tafelvoetbal kan alleen met de spitsen gespeeld worden. Als hulpmiddel kan een balk achter de spitsen worden geplaatst, zodat de bal in bereik van de spitsen blijft, zie Figuur 43.

Figuur 43: Speelveld spitsen tegen de keeper

Pagina 39 van 51

## 6. Troubleshooting sectie en instructies om problemen op te lossen

In dit hoofdstuk zijn bij verschillende problemen instructies gegeven voor de mogelijke oplossing. Hierbij wordt aangenomen dat alle installatie instructies (zie vanaf pagina 7) succesvol zijn uitgevoerd.

In het geval dat het betreffende probleem niet in dit hoofdstuk aanwezig is, probeer dan zelf de oplossing via het internet op te zoeken en/of een docent te vragen naar een mogelijke oplossing. Als het probleem dan nog steeds voordoet, is contact mogelijk met de gegeven contactpersonen op pagina 44.

Wanneer er een probleem is opgelost wat ontbreekt in dit hoofdstuk, gelieve het betreffende probleem en oplossing aan te vullen in de onderstaande tabellen. Verhoog daarnaast de revisie versie en werk deze bij.

## 6.1 Jetson Nano foutmeldingen

In Tabel 8 zijn mogelijke oplossingen weergegeven die betrekking hebben op problemen met de Jetson Nano.

Tabel 8 Troubleshooting Jetson Nano foutmeldingen

Probleem | Mogelijke oorzaak | Mogelijke oplossing
No module … | Virtual environment is niet geactiveerd. | Voer in de terminal het volgende commando uit: cd ~ source ft_env/bin/activate
| Module is niet geïnstalleerd. | Zorg er voor dat virtual environment ‘ft_env’ geactiveerd is en voer in de terminal het volgende commando uit: sudo pip3 install *naam ontbrekende module* Wanneer dit het probleem heeft verholpen, vul het gebruikte commando aan bij stap 4 van installeren Jetson Nano op pagina 12 en verhoog de revisie versie.
No module named ‘Box2D.Box2D’ | Bouwen Box2D is mislukt of library is corrupt geraakt. | Zorg er voor dat virtual environment ‘ft_env’ geactiveerd is en voer stap 5 uit van installeren Jetson Nano op pagina 12.
No module named ‘TensorFlow’ | Installatie TensorFlow is mislukt of library is corrupt geraakt. | Zorg er voor dat virtual environment ‘ft_env’ geactiveerd is en voer stap 7 uit van installeren Jetson Nano op pagina 13.
‘…’ object has no attribute ‘…’ | Python bestanden ontbreken of zijn niet in de juiste map. | Bekijk de repository op: https://github.com/CookieLover22/FoosTronics Controleer of er bestanden ontbreken of op de juiste plaats staan op de Jetson Nano. Wanneer dit het geval is, vul de ontbrekende bestanden aan.
No camera detected | Camera is nadat de Jetson Nano is opgestart aangesloten. | Herstart de Jetson Nano door in de terminal het volgende commando uit te voeren: reboot

Pagina 40 van 51

## 6.2 Overig

In Tabel 9 zijn mogelijke oplossingen weergegeven voor overige problemen.

Tabel 9 Troubleshooting overig

Probleem | Mogelijke oorzaak | Mogelijke oplossing
Bal wordt niet of foutief gedetecteerd | Belichting in omgeving is veranderd of kalibratie is onjuist uitgevoerd. | Sluit de applicatie af en start deze vervolgens opnieuw op volgens de gebruikersinstructies op pagina 37 vanaf stap 7.
Stang is losgelaten van mechanica | Verbindingsstuk is heel, maar is niet verbonden aan axiale motor. | Duw het verbindingsstuk stevig op de axiale motor as. Als deze verbinding na korte tijd weer loslaat, zal het verbindingsstuk vervangen moeten worden. Zie voor 3D print bestand in map “3D-prints” met bestandsnaam “Verbindingstuk_handel_v2_m5.STL” op de repository: https://github.com/CookieLover22/FoosTronics
| Verbindingsstuk gebroken. | Het verbindingsstuk zal vervangen moeten worden. Zie voor 3D print bestand in map “3D-prints” met bestandsnaam “Verbindingstuk_handel_v2_m5.STL” op de repository: https://github.com/CookieLover22/FoosTronics
Keeper staat axiaal verkeerd of draait niet | De gyroscoop wordt niet of verkeerd uitgelezen. | Controleer of de verbinding tussen de Jetson Nano en de gyroscoop juist is aangesloten. Vervang de gyroscoop en/of de bekabeling.
| De axiale motor is stapverlies aan het oplopen door onvoldoende voltage en/of stroom. | Zet op de spanningsbron van de axiale motor de voltage op 12V en de stroombegrenzer op 1A.
| Hendel klemmen zitten los. | Monteer de hendel klemmen opnieuw volgens de instructies van stap Fout! Verwijzingsbron niet gevonden. tot en met Fout! Verwijzingsbron niet gevonden. van Monteren van de axiale mechanica op pagina Fout! Bladwijzer niet gedefinieerd..
| Hendel klemmen gebroken. | De hendel klemmen zullen vervangen moeten worden. Zie voor 3D print bestand in map “3D-prints” met bestandsnaam “Mal_handel_2x.STL” op de repository: https://github.com/CookieLover22/FoosTronics
Motor bij laterale mechanica blijft doordraaien bij limiet | Limietsensors staan te ver van tandheugelplatvorm. | Zorg dat de limietsensors en tandheugelplatvorm juist gemonteerd zijn volgens Monteren van de laterale mechanica op pagina 21.
Keeper blijft lateraal hangen en zijn niet bij de limietsensoren gekomen | De laterale motor is stapverlies aan het oplopen door onvoldoende voltage en/of stroom. | Zet op de spanningsbron van de laterale motor de voltage op 12V en de stroombegrenzer op 1A.
| Geleiders in ladedragers zijn stroef. | Volg de instructies van hoofdstuk Smeren op pagina 42.

Pagina 41 van 51

Pagina 42 van 51

## 7.Onderhoudsinformatie

In dit hoofdstuk zal vermeld worden hoe de hard- en software van de voetbaltafel wordt onderhouden.

## 7.1 Onderhoud aan de mechanica

Naarmate de mechanica ouder wordt, zullen er gebreken optreden. Om problemen te voorkomen zal gekeken worden naar schoonmaak- en smeerinstructies en als laatste een onderhoudsplan.

Schoonmaken
Na verloop van tijd zullen er stofresten ontstaan op de tafel. Om de tafel in goede staat te houden is er een schoonmaakplan opgesteld.

Voor het spelen:
- Stof de camera doormiddel van een doekje met alcohol of brilspray. Dit zorgt ervoor dat de bal duidelijk kan worden herkent.
- Stof de tafel af met een vochtig doekje.
- Zorg dat de bak van de voetbaltafel stofvrij is. Dit kan gedaan worden doormiddel van een stofzuiger, kruimeldief of een vochtig doekje.

Na het spelen:
- Reinig de handvatten met alcohol. Dit zorgt ervoor dat de tafel hygiënisch blijft.

Smeren:
- Controleer een keer per week of de stangen goed glijden. Wanneer dit niet zo is, vet de stangen in met WD40.Tijdens het smeren is het aan te raden de stangen te bewegen, zodat het smeermiddel evenredig wordt verspreid.
- Smeer eens per week de kogellagers in de ladegeleiders met WD40. Dit kan gedaan worden door de ladegeleider uit te schuiven (naar de tafel) en WD40 aan te brengen aan de zijkanten van de geleider. Dit is weergegeven in Figuur 44 met de rode pijlen.
- Eens per week moet gecontroleerd worden of de tandheugel ingevet is. Indien dit niet het geval is, moet WD40 op de tandheugel worden aangebracht.

Figuur 44 Kogellager in de ladegeleider.

Pagina 43 van 51

## 7.2 Onderhoudsplan

Om de kwaliteit van het product te waarborgen, is het aan te raden om voor opendagen een visuele inspectie te houden. In Bijlage 1 staat een onderhoudsplan met daarin een checklist met globale onderdelen. Indien een van deze onderdelen de inspectie faalt, mag de voetbaltafel niet in bedrijf worden genomen. Nadat het desbetreffende onderdeel is vervangen, moet het onderhoudsplan opnieuw worden uitgevoerd voordat het product in bedrijf mag worden genomen.

## 7.3 Software

Wanneer de tafel een tijd niet is gebruikt, is het van belang dat de nieuwste software update op het systeem wordt gezet. Per punt zal stapsgewijs beschreven worden hoe de nieuwste versie vanaf Github kan worden gehaald:
1. Zet de Jetson Nano aan en log in.
2. Open een terminal (ctrl+shift+t)
3. Ga naar de map doormiddel van: cd ../FoosTronics
4. Git checkout master
5. Git pull

De bestanden zijn nu up-to-date met de laatste stabiele versie.

Pagina 44 van 51

## 8 Contact details

Wanneer vragen of onduidelijkheden zijn over verschillende onderwerpen zijn wij te bereiken via mail. In Tabel 10 zijn van alle onderwerpen de contactgegevens weergegeven.

Wanneer het project wordt voortgezet door een ander groep, is het van belang dat de mailgegevens worden aangepast.

Tabel 10 Contactgegevens studenten.

Onderwerp | Mail
Mechanica/ stappenmotor | Kelvin.sweere@student.hu.nl
Simulatie | Daniel.boon@student.hu.nl
Beeldherkenning | Sipke.velinga@student.hu.nl
Git | Chileam.bohnen@student.hu.nl

Pagina 45 van 51

## Lijst van afkortingen en begrippen

Artificiële intelligentie | Wetenschap die zich bezighoudt met het creëren van een artefact dat een vorm van intelligentie vertoont
Axiaal | De roterende beweging voor het schieten van de keeper
Beeldherkenning | Softwarematige bewerking op digitale beelden
Displayport | Audio- en videostandaard
Extrapolatie | Op grond van een bekende reeks gegevens conclusies trekken buiten het meetgebied
Github | Website waarop software en documenten geplaatst kunnen worden
GPIO | General-purpose input/output
HDMI | High-definition multimedia interface
I²C | synchrone, seriële bus, ontwikkeld voor datacommunicatie tussen microprocessoren en andere IC's
I²S | Seriële bus voor het verbinden van digitale audioapparatuur met elkaar
IO-connector | Input/output connector
JST | Japanese solderloze terminals
Lateraal | De lineaire beweging van de keeper voor het doel
M.2 Key E | Connectie op de NVIDIA Jetson Nano voor de M.2 wifimodule
MIPI CSI-2 DPHY lanes | Connectie tussen camera en applicatie processor
NVIDIA JETSON NANO DEVELOPER KIT | Mini computer
OpenCV | Open source computer vision
Pip | Pakket manager voor Python pakketten
PyBox2D | 2D bibliotheek met natuurkundige functies voor spellen en simulaties
Reinforcement learning | Toepassing van artificiële intelligentie

Pagina 46 van 51

Repository | Benaming voor een online archief (Github)
Rufus 3.8 | Windows-programma waarmee zelfstartende usb-sticks kunnen worden gemaakt
SPI | Seriele Periferele Interface
Stappenmotor | Motor waarvan de hoekverdraaiing nauwkeurig te bepalen is
Tandheugel | Rechthoekige staaf die aan één kant is voorzien van vertanding zoals een tandwiel
TensorFlow | End-to-end open source machine learning platform
UART | Universele asynchrone receiver-transmitter
USB | Universele seriële bus
Virtual environment | Een softwareomgeving waarin andere Python versies en librarys gebruikt kunnen worden waarbij de root of andere virtual environments onaangepast blijven
WD40 | Waterverdrijvende kruipolie spray

Pagina 47 van 51

## Lijst van figuren

Figuur 2: Zij aanzicht Jetson Nano met links de 8-pins header en in het midden CSI-2 camera

Figuur 21 Opbouw eindschakelaarsbord. Hierbij is links een schuin vooraanzicht en rechts een

Pagina 48 van 51

## Lijst van tabellen

Pagina 49 van 51

## Bibliografie

Bloom, L. (2019, januari 12). How to Write a Great User Manual in 12 Steps. Retrieved from dozuki: https://www.dozuki.com/blog/2017/01/12/how-to-write-a-user-manual
Human Benchmark. (2019). Reaction Time Test. Retrieved oktober 10, 2019, from https://www.humanbenchmark.com/tests/reactiontime
Noun Project Inc. (2020). Icons for everything. 2020. Utrecht. Retrieved januari 8, 2020, from https://thenounproject.com/: https://thenounproject.com/
Vermeulen, F. (2019, februari 15). User Manual Template Case Study: Startup Creates a Compliant Manual (in Less Than 3 Weeks). Retrieved from instrktiv: https://instrktiv.com/en/user-manual-template/

Pagina 50 van 51

## Bijlage 1

# | Checklist correctief onderhoud | Streep door

1 | Zit er een scheur in de hendel klem? | Ja / nee
2 | Zit er een scheur in het verbindingsstuk? | Ja / nee
3 | Zit de camera los in de camerabehuizing? | Ja / nee
4 | Zit er een scheur in de gyroscoophouder? | Ja / nee
5 | Hebben de stangen een kromming groter dan 10 graden? | Ja / nee
6 | Zit er een scheur in het camerastatief? | Ja / nee
7 | Kan de stappenmotor niet los komen van de tandheugel? | Ja / nee
8 | Is de tandheugel versleten? | Ja / nee
9 | Kan het eindschakelaarsbord worden opgetild van de tafel? | Ja / nee
10 | Zit de ladendrager en tandheugel los? | Ja / nee

Indien één van deze onderdelen met ‘ja’ is beantwoord, moet dit onderdeel worden vervangen. Na het vervangingen is het van belang dat de checklist opnieuw wordt uitgevoerd.

# | Oplossing

1 | Print hendel klemmen opnieuw (zorg hierbij dat de nieuwste versie wordt gebruikt (en op elkaar aansluit).
2 | Print verbindingsstuk opnieuw (zorg hierbij dat de nieuwste versie wordt gebruikt (en op elkaar aansluit).
3 | Print camerabehuizing opnieuw (zorg hierbij dat de nieuwste versie wordt gebruikt (en op elkaar aansluit).
4 | Print gyroscoophouder opnieuw (zorg hierbij dat de nieuwste versie wordt gebruikt (en op elkaar aansluit).
5 | Verwijder de stangen en buig deze weer recht. Indien dit niet meer kan, zorg dat er nieuwe stangen worden gekocht.
6 | Vervang het camerastatief.
7 | Zorg dat de stappenmotor wordt uitgelijnd met de tandheugel. Lees “” voor verdere informatie.
8 | Vervang de tandheugel. Indien deze niet meer op voorraad zijn, kan een nieuwe besteld worden op: http://nl.aliexpress.com/item/32400417811.html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,searchweb201602_7,searchweb201603_55 (http://nl.aliexpress.com/item/32400417811.html)
9 | Zorg dat het eindschakelaarsbord aan het tafelblad wordt bevestigd. Verdere informatie is te vinden in “Monteren van de axiale mechanica”.
10 | Bevestig de ladendrager via het stuk “Monteren van de laterale mechanica”.


Pagina 51 van 51

## Bijlage 2

Figuur 45 Afmetingen houten plaat voor verbinding camera met het frame.

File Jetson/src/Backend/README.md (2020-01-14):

# AI_Foosball_Simulation
AI Foosball Simulation

Installatie instructies Windows. Hierbij wordt vanuit gegaan dat je al conda en pip kan gebruiken in je CMD (of Anaconda Prompt):
1. Zorg voor een nieuwe environment in conda (dit is niet noodzakelijk, maar zorgt wel dat je python versiebeheer niet in de komt).
Tikkel hiervoor in je CMD (python 3.6 is noodzakelijk):

    ```bash
    conda create -n py36 python=3.6
    ```
2. Activeer deze environment (deze moet iedere keer in je CMD in tikkelen als je de simulatie wilt opstarten):

    ```bash
    conda activate py36
    ```

3. Nu moet pyBox2D gecloned en gebuild worden. Zet de CMD in de map waar je de lib wilt bouwen:
    ```bash
    CD C:\de\locatie\van\de\map\die\je\hebt\gekozen
    ```
4. Clone pyBox2D:
    ```bash
    git clone https://github.com/pybox2d/pybox2d
    ```
5. Ga die map in:
    ```bash
    cd pybox2d
    ```
6. Build die hele handel:
    ```bash
    python setup.py build
    ```
7. Installeer die gebuilde handel:
    ```bash
    python setup.py install
    ```
8.installeer dan de volgende benodigde libs (de versie nummer die Daniël gebruikt staat erbij, maar is niet noodzakelijk te gebruiken als al werkt):

    | Backend        | Install                                                       | Homepage                             |
    | -------------  | ------------------------------------------------------------- | ------------------------------------ |
    | pygame (2.0.0) | `pip install pygame`                                          | http://pygame.org                    |  
    | pyqt4 (4.10.4) | `conda install pyqt=4`                                        | https://www.riverbankcomputing.com/  |
    | pyglet         | `pip install pyglet`                                          | http://pyglet.org                    |
    | opencv-python  | `pip install opencv-python`                                   | http://opencv.org                    |
    | (3.4.6.27)     |                                                               |                                      |
    |  swig-3.0.12   | `conda install swig`                                          | http://www.swig.org/                 |

9. Clone nu de repo met de simulatie als dat nog niet gedaan is (het gebruik van een Git GUI is hiervoor geadviseerd)

10. Zet de CMD in de map waar de simulatie repo staat:
    ```bash
    CD C:\de\locatie\van\de\map\waarin\de\simulatie\staat
    ```
11. ga dan naar deze map:
    ```bash
    CD keeper_sim
    ```
12. Als alle stappen van hierboven hebt doorgeworsteld, zou zou de simulatie moeten draaien met deze laatste commando:
    ```bash
    python keeper_sim.py
    ```
13. Als de bovenstaande commando werkt, zal de simulatie ook werken in je Python IDE naar voorkeur (als je gemaakte conda environment in kan werken)

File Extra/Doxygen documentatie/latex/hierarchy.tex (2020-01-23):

\doxysection{Class Hierarchy}
This inheritance list is sorted roughly, but not completely, alphabetically\+:\begin{DoxyCompactList}
\item \contentsline{section}{src.\+Ball\+Detect.\+Ball\+Detection}{\pageref{classsrc_1_1_ball_detect_1_1_ball_detection}}{}
\item \contentsline{section}{src.\+Backend.\+Beeld\+Koppeling.\+Beeld\+Koppeling}{\pageref{classsrc_1_1_backend_1_1_beeld_koppeling_1_1_beeld_koppeling}}{}
\item \contentsline{section}{src.\+Keeper\+Sim.\+Control}{\pageref{classsrc_1_1_keeper_sim_1_1_control}}{}
\item \contentsline{section}{src.\+Controller.\+Controller}{\pageref{classsrc_1_1_controller_1_1_controller}}{}
\item \contentsline{section}{src.\+Backend.\+Deep\+Q\+Learning.\+D\+Q\+L\+Base}{\pageref{classsrc_1_1_backend_1_1_deep_q_learning_1_1_d_q_l_base}}{}
\item \contentsline{section}{src.\+Backend.\+Deep\+Q\+Learning.\+D\+Q\+Network}{\pageref{classsrc_1_1_backend_1_1_deep_q_learning_1_1_d_q_network}}{}
\item \contentsline{section}{src.\+Backend.\+U\+S\+B.\+Driver}{\pageref{classsrc_1_1_backend_1_1_u_s_b_1_1_driver}}{}
\item \contentsline{section}{src.\+Find\+Contours.\+Find\+Contours}{\pageref{classsrc_1_1_find_contours_1_1_find_contours}}{}
\item \contentsline{section}{main.\+Foostronics}{\pageref{classmain_1_1_foostronics}}{}
\item \contentsline{section}{src.\+Image\+Capture.\+Image\+Capture}{\pageref{classsrc_1_1_image_capture_1_1_image_capture}}{}
\item \contentsline{section}{src.\+Backend.\+Deep\+Q\+Learning.\+Memory}{\pageref{classsrc_1_1_backend_1_1_deep_q_learning_1_1_memory}}{}
\item \contentsline{section}{src.\+Backend.\+M\+P\+U6050.\+M\+P\+U6050}{\pageref{classsrc_1_1_backend_1_1_m_p_u6050_1_1_m_p_u6050}}{}
\item object\begin{DoxyCompactList}
\item \contentsline{section}{src.\+Backend.\+Settings.\+fw\+Settings}{\pageref{classsrc_1_1_backend_1_1_settings_1_1fw_settings}}{}
\end{DoxyCompactList}
\item b2\+Draw\+Extended\begin{DoxyCompactList}
\item \contentsline{section}{src.\+Backend.\+Pygame\+Framework.\+Pygame\+Draw}{\pageref{classsrc_1_1_backend_1_1_pygame_framework_1_1_pygame_draw}}{}
\end{DoxyCompactList}
\item Enum\begin{DoxyCompactList}
\item \contentsline{section}{src.\+Backend.\+U\+S\+B.\+Commands}{\pageref{classsrc_1_1_backend_1_1_u_s_b_1_1_commands}}{}
\end{DoxyCompactList}
\item Framework\begin{DoxyCompactList}
\item \contentsline{section}{src.\+Keeper\+Sim.\+Keeper\+Sim}{\pageref{classsrc_1_1_keeper_sim_1_1_keeper_sim}}{}
\end{DoxyCompactList}
\item Framework\+Base\begin{DoxyCompactList}
\item \contentsline{section}{src.\+Backend.\+Pygame\+Framework.\+Pygame\+Framework}{\pageref{classsrc_1_1_backend_1_1_pygame_framework_1_1_pygame_framework}}{}
\end{DoxyCompactList}
\end{DoxyCompactList}

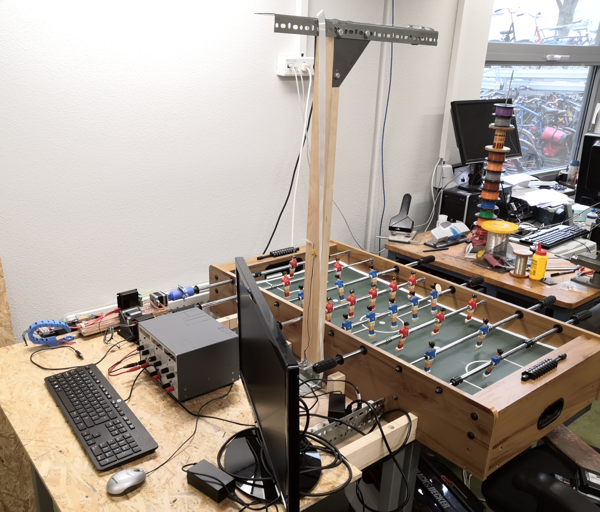
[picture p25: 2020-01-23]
Extra/Promo/Afbeeldingen/zijkant_tafel.jpg

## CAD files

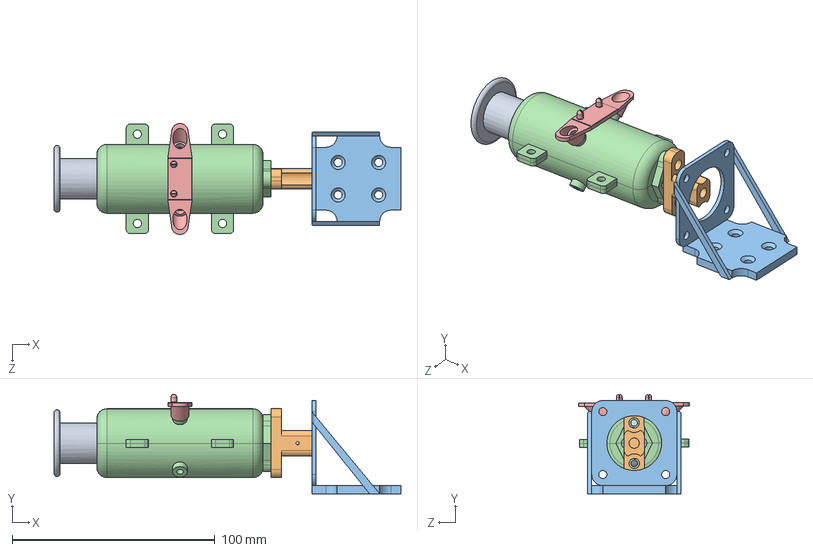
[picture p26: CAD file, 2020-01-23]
Extra/3D-tekeningen/AssembliesEtc/TestAssembly.SLDASM
171.1 x 49.1 x 54.8 mm
Verbindingstuk_handel
motor_houder
Mal_handel v2 x 2
houder

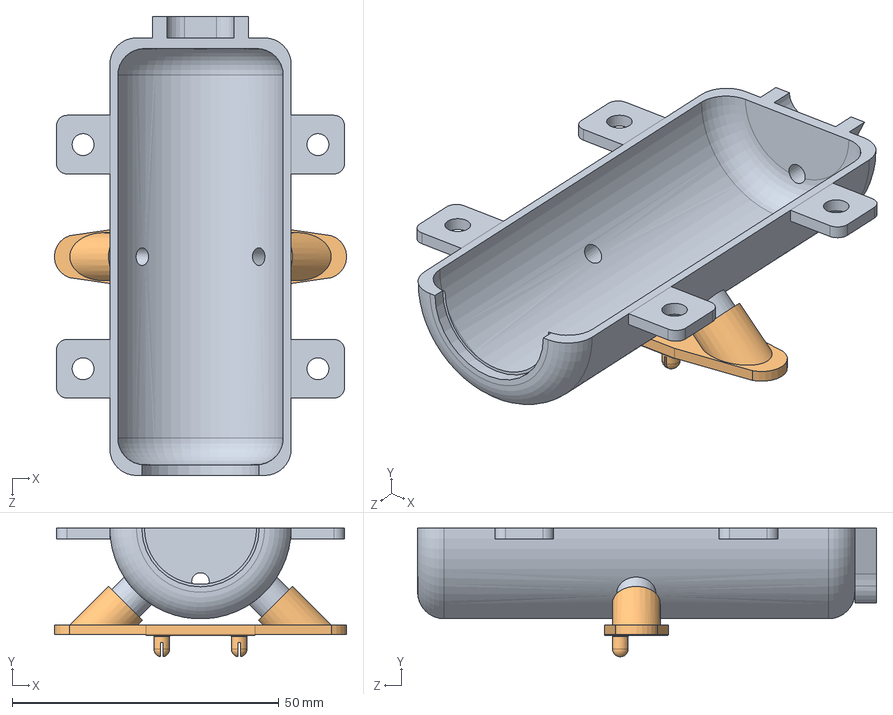
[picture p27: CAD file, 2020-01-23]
Extra/3D-tekeningen/Extra/Assembly_hendel+gyro.SLDASM
54.8 x 24.1 x 86.0 mm
Mal_handel v2
houder

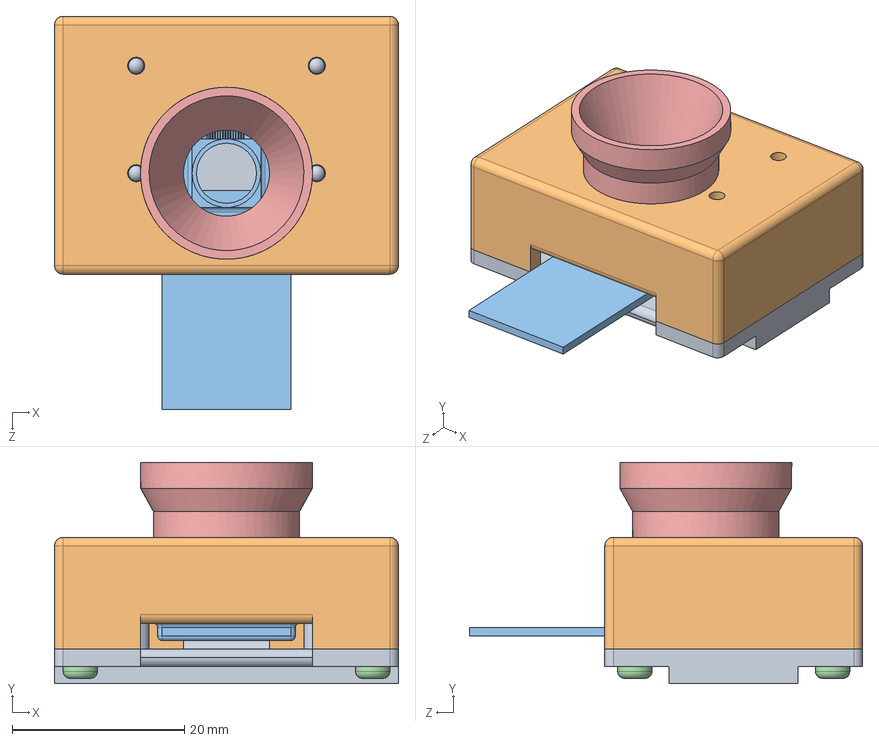
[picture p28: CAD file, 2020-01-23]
Extra/3D-tekeningen/AssembliesEtc/CamHousingAssembly.SLDASM
40.0 x 25.7 x 45.8 mm
Camera case bottomV3
Camera Case Top
Raspberry Pi
pan head tapping screw_am x 4

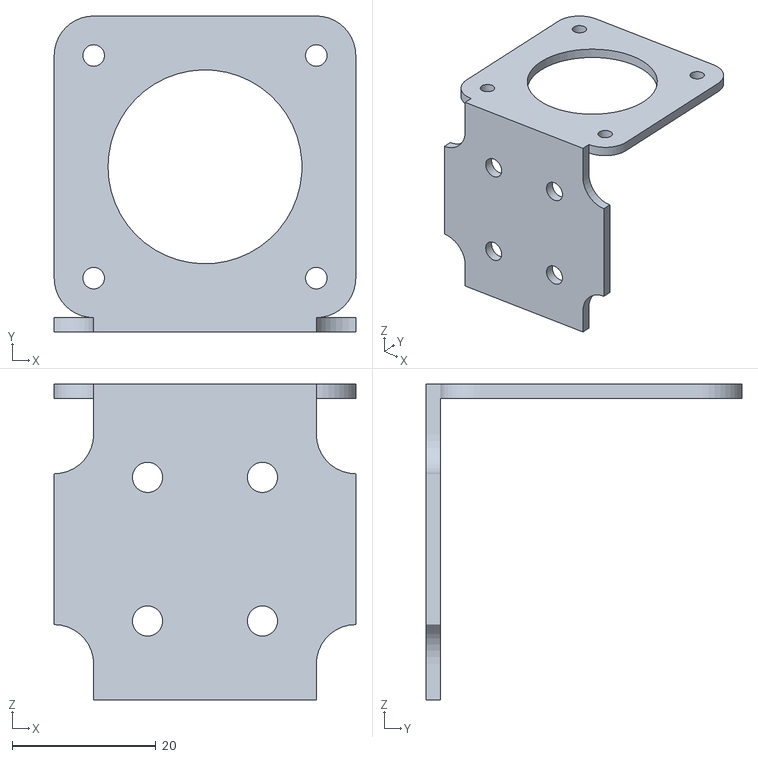
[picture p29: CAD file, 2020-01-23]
Extra/3D-models/MotorHouder 17PU-H502.STL
42.0 x 44.0 x 44.0

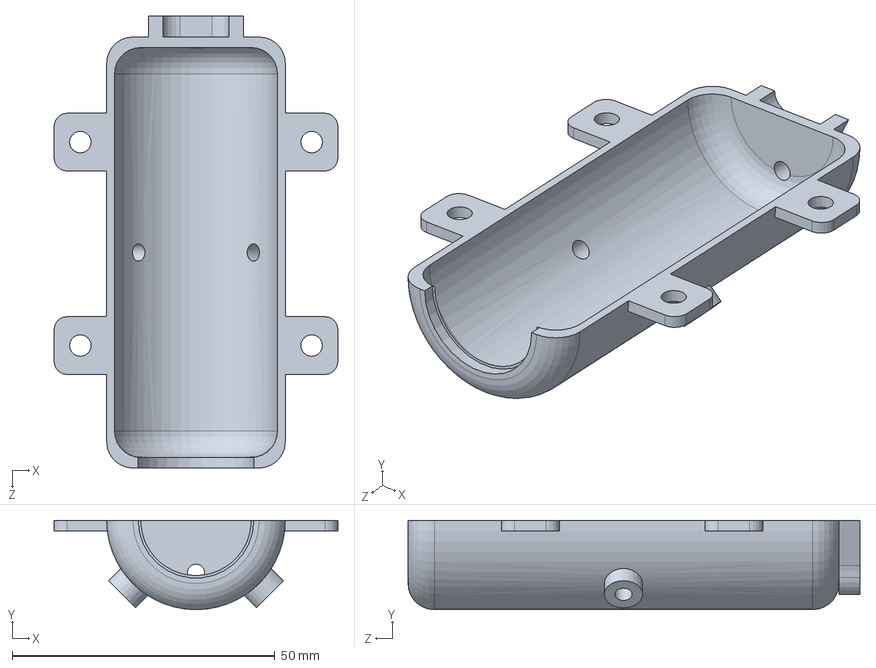
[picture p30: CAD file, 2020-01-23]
Extra/3D-tekeningen/MalHendel.SLDPRT
54.0 x 17.0 x 86.0 mm

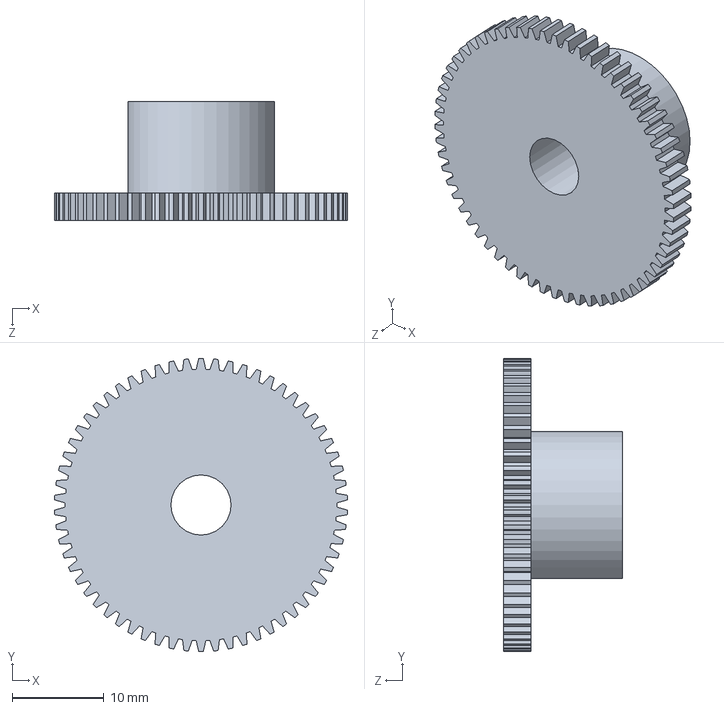
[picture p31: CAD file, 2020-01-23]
Extra/3D-tekeningen/Tandwiel/Tandwiel V3.SLDPRT
31.9 x 31.9 x 13.0 mm

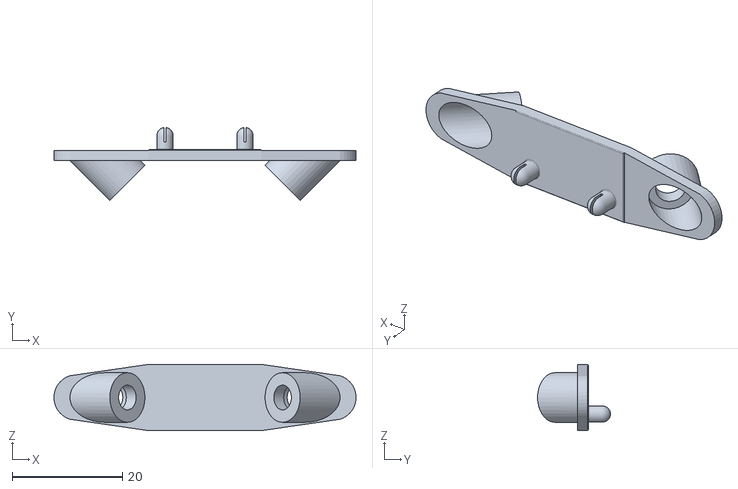
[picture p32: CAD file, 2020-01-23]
Extra/3D-models/Gyroscoophouder.STL
54.7 x 13.2 x 12.0

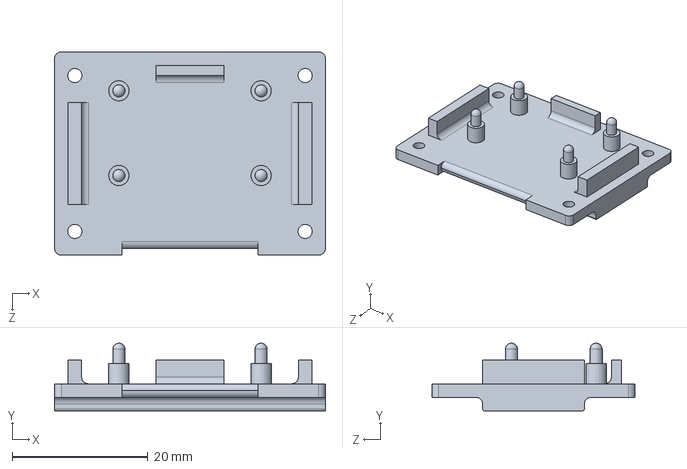
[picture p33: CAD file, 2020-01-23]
Extra/3D-tekeningen/CamCaseBottom.SLDPRT
40.0 x 10.0 x 30.0 mm

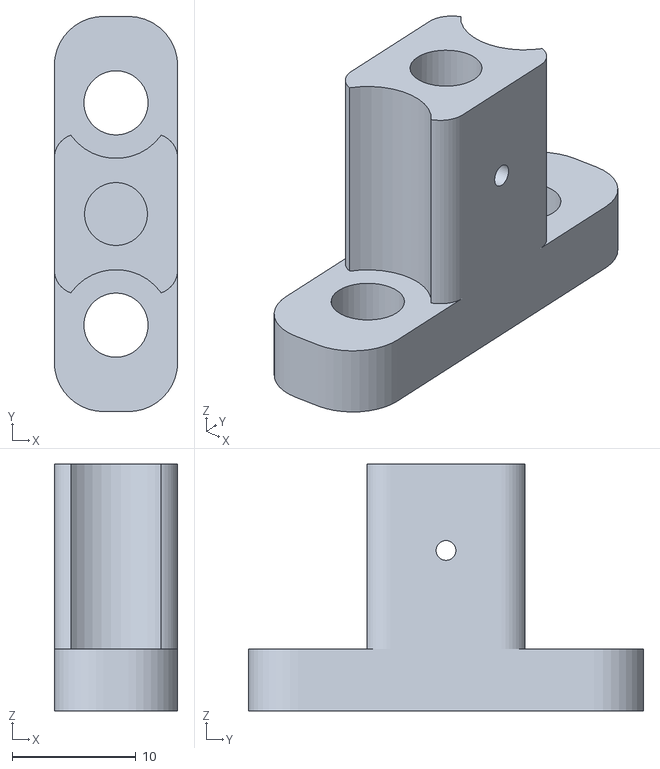
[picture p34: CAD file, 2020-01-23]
Extra/3D-models/VerbindingstukHandel.STL
10.0 x 32.0 x 20.0

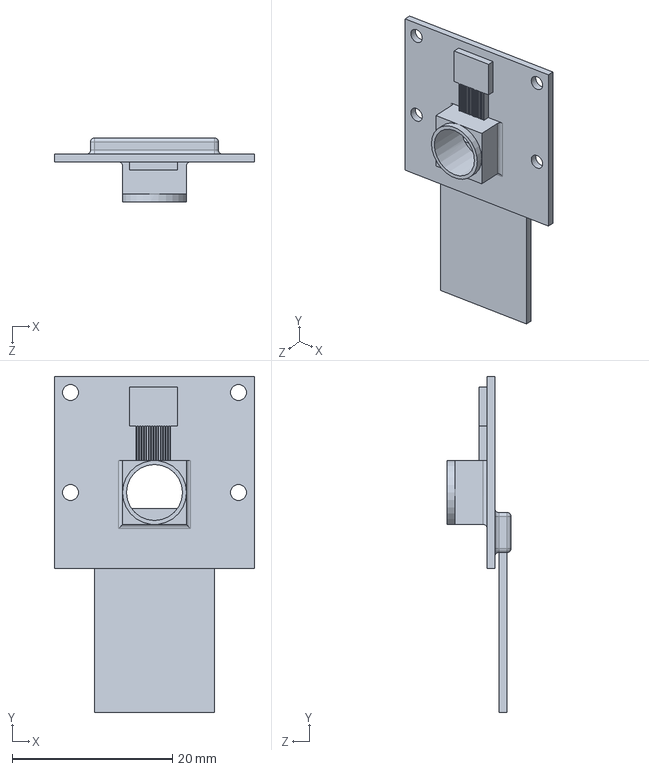
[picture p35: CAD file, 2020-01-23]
Extra/3D-tekeningen/AssembliesEtc/Raspberry Pi.SLDPRT
25.0 x 42.0 x 8.00 mm

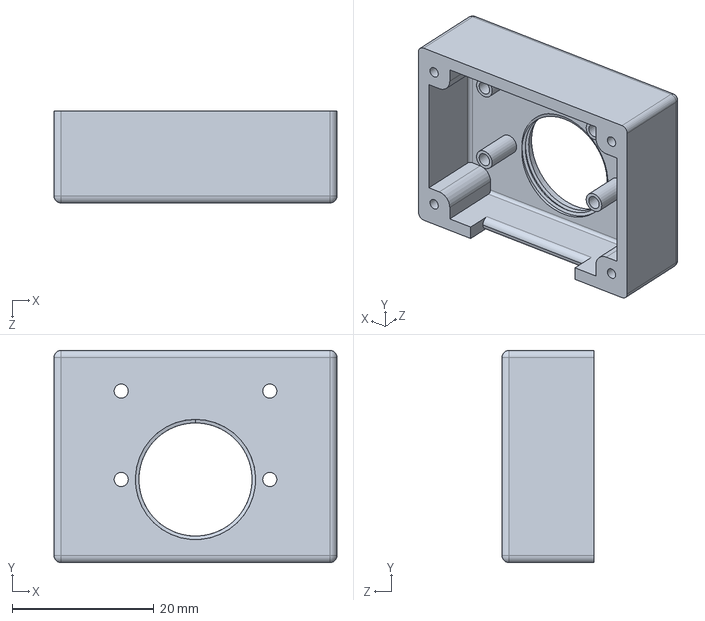
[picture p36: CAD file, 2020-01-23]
Extra/3D-tekeningen/CamCaseTop.SLDPRT
40.0 x 30.0 x 13.0 mm

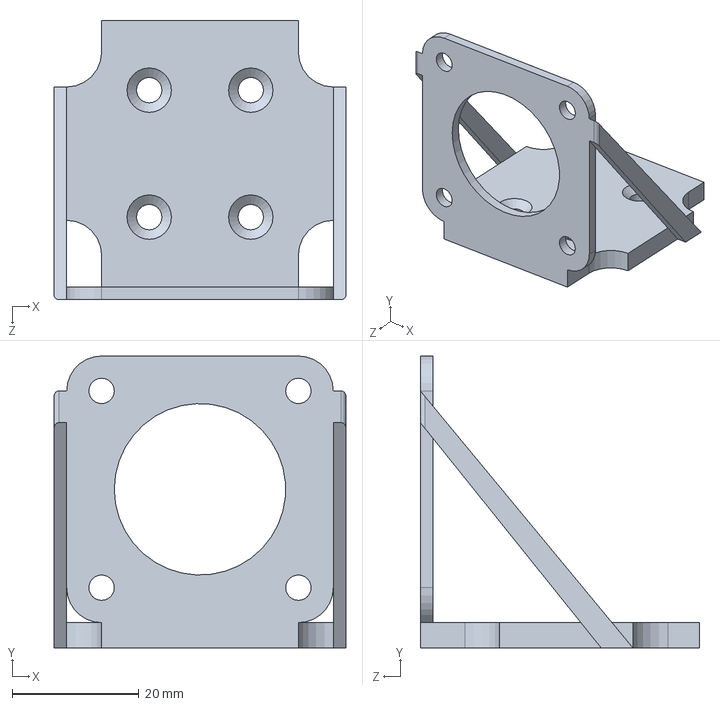
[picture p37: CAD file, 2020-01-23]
Extra/3D-tekeningen/MotorHouder.SLDPRT
46.0 x 46.0 x 44.0 mm

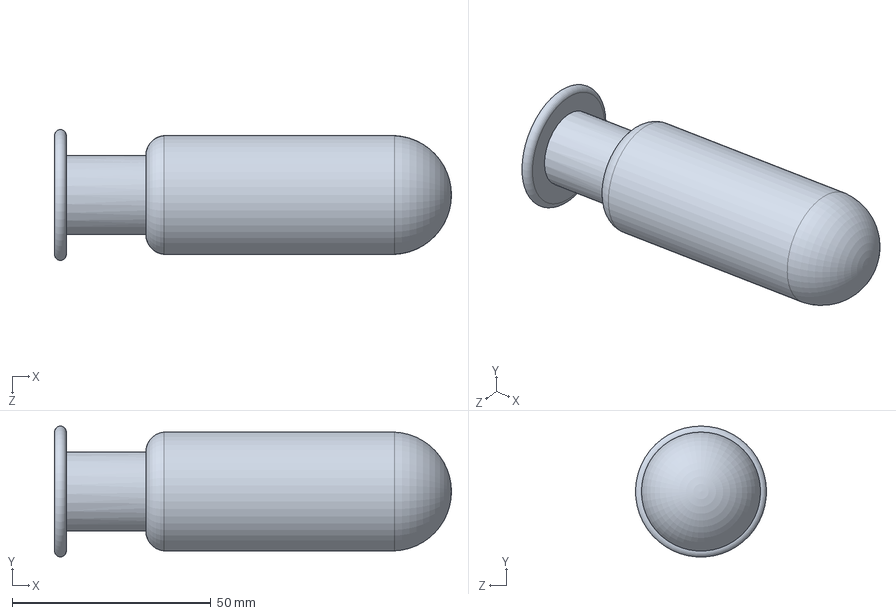
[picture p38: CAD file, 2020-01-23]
Extra/3D-tekeningen/AssembliesEtc/TafelvoetbaltafelHendel.SLDPRT
100.0 x 33.0 x 33.0 mm

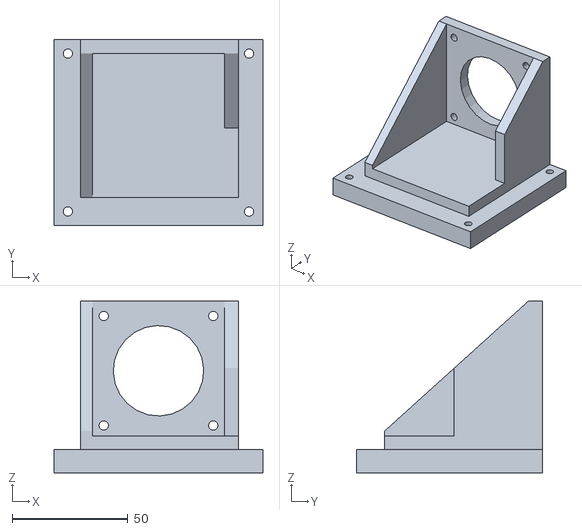
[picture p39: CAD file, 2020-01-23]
Extra/3D-models/Motorhouder KH56JM2.stl
90.1 x 80.1 x 74.1

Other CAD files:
Extra/3D-tekeningen/AssembliesEtc/AssemblyHendelGyro.SLDASM
Extra/3D-models/CamCaseTop.STL
Extra/3D-models/CamCaseBottom.STL
Extra/3D-tekeningen/GyroscoopHouder.SLDPRT
Extra/3D-models/Eindschakelaarbord.stl
Extra/3D-models/Grondplaat 1mm.stl
Extra/3D-models/MalHendel.STL
Extra/3D-models/Tandwiel.STL
Extra/3D-tekeningen/AssembliesEtc/lens.SLDPRT
Extra/3D-tekeningen/Laterale beweging/Eindschakelaarbord.skp
Extra/3D-tekeningen/Laterale beweging/Grondplaat 1mm.skp
Extra/3D-tekeningen/Laterale beweging/Motorhouder.skp
Extra/3D-tekeningen/VerbindingstukHendel.SLDPRT

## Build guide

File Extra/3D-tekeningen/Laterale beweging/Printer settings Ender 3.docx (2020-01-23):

0.6mm nozzle petg motorhouder en grondplaat (nope)

Layer 0.3mm, 3 walls, infill 40% cubic, print temp 240, build plate temp 60, retraction distance 4, retraction speed 40mm/s, print speed 40mm/s, travel speed 150mm/s, init layer speed 15mm/s, slower layers 2, fan speed 50%, regular speed at layer 3, adhesion skirt

0.4mm nozzle petg motorhouder en grondplaat zusterstape glasplaat (trekt krom, warping)

Layer 0.2mm, init layer height 0.3mm, line width 0.4mm, wall thickness 0.8mm, 2 walls, infill 40% grid, print temp 235, build plate temp 60, retraction distance 10, retraction speed 40mm/s, print speed 40mm/s, travel speed 150mm/s, init layer speed 40mm/s, slower layers 2, fan speed 50%, regular speed at layer 3, adhesion skirt

0.4mm nozzle petg motorhouder en grondplaat schilderstape glasplaat (gelukt)

Layer 0.2mm, init layer height 0.3mm, line width 0.4mm, wall thickness 0.8mm, 3 walls, infill 40% grid, print temp 235, build plate temp 60, buil plate init temp 70, retraction distance 10, retraction speed 40mm/s, print speed 40mm/s, travel speed 150mm/s, init layer speed 40mm/s, slower layers 2, fan speed 50%, regular speed at layer 2, adhesion brim

0.4mm nozzle petg eindschakelaarsbord bovendeel v5 + Grondplaat 4mm schilderstape glasplaat

Layer 0.3mm, init layer height 0.3mm, line width 0.4mm, wall thickness 0.8mm, 3 walls, top thickness 2.4mm, infill 30% zig zag, print temp 235, build plate temp 60, buil plate init temp 70, retraction distance 10, retraction speed 40mm/s, print speed 40mm/s, travel speed 150mm/s, init layer speed 25mm/s, slower layers 2, fan speed 50%, regular speed at layer 2, adhesion brim

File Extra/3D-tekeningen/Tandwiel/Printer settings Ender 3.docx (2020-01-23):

0.6mm nozzle petg tandwiel (niet goed)

Layer 0.3mm, shell 3 walls, infill 70% lines, print temp 240, initial print temp 250, build plate temp 60, retraction distance 4mm, retraction speed 40mm/s, print speed 30mm/s, travel speed 150mm/s, init layer speed 15mm/s, slower layers 2, fan speed 50%, initial fan speed 0, regular at layer 3, adhesion skirt

0.2mm nozzle petg tandwiel (niet goed)

Layer 0.1mm, shell 8 walls, infill 60% lines, print temp 240, build plate temp 60, retraction distance 6.5mm, retraction speed 25mm/s, print speed 40mm/s, travel speed 150mm/s, init layer speed 15mm/s, slower layers 2, fan speed 50%, initial fan speed 0, regular at layer 3, adhesion Brim

0.2mm nozzle petg tandwiel schilderstape ondergrond

Layer 0.2mm, init layer 0.3mm, lind width 0.4mm, wall thickness 0.8mm, wall line count 2, infill 70% grid, print temp 235, build plate temp 30, retraction distance 10mm, retraction speed 40mm/s, print speed 40mm/s, travel speed 150mm/s, init layer speed 35mm/s, slower layers 2, fan speed 50%, initial fan speed 0, regular at layer 2, adhesion skirt

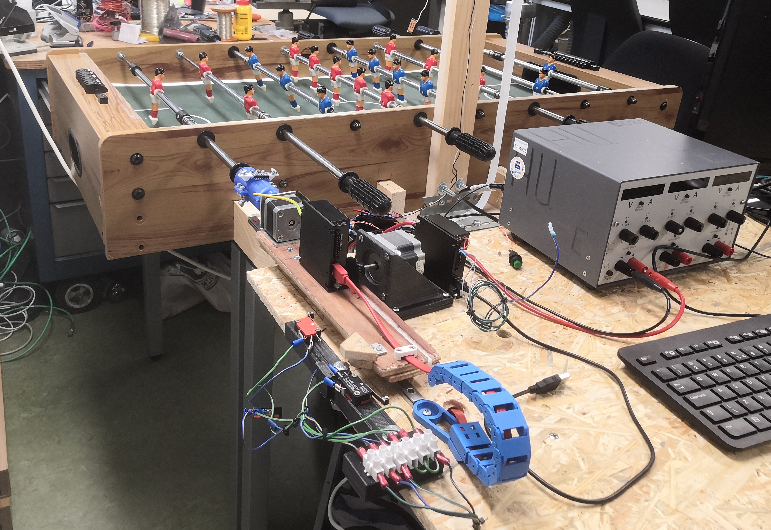
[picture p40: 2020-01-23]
Extra/Promo/Afbeeldingen/tafel_plus_constructie.jpg

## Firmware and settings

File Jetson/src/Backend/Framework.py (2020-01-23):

""" 
    Geraamte voor de Box2D simulatie.
    De basis van het geraamte is FrameworkBase. Kijk bij de hulp sectie hiervan voor meer informatie. 
    
    File:
        Framework.py
    Date:
        22-1-2020
    Version:
        1.12
    Modifier:
        Daniël Boon
    Used_IDE:
        Visual Studio Code (Python 3.6.7 64-bit)
    Schematic:
        -
    Version management:
        1.0:
            Headers toegevoegd
        1.1:
            Commentaar toegevoegd in Google docstring format. 
        1.11:
            Spelling en grammatica nagekeken
            Engels vertaald naar Nederlands
        1.12:
            Commentaar afgemaakt
"""

#!/usr/bin/env python
# -*- coding: utf-8 -*-
#
# C++ version Copyright (c) 2006-2007 Erin Catto http://www.box2d.org
# Python version by Ken Lauer / sirkne at gmail dot com
#
# This software is provided 'as-is', without any express or implied
# warranty.  In no event will the authors be held liable for any damages
# arising from the use of this software.
# Permission is granted to anyone to use this software for any purpose,
# including commercial applications, and to alter it and redistribute it
# freely, subject to the following restrictions:
# 1. The origin of this software must not be misrepresented; you must not
# claim that you wrote the original software. If you use this software
# in a product, an acknowledgment in the product documentation would be
# appreciated but is not required.
# 2. Altered source versions must be plainly marked as such, and must not be
# misrepresented as being the original software.
# 3. This notice may not be removed or altered from any source distribution.

#from .PygameFramework import PygameFramework as Framework
from .Settings import fwSettings

from time import time

from Box2D.Box2D import (b2World, b2AABB, b2CircleShape, b2Color, b2Vec2)
from Box2D.Box2D import (b2ContactListener, b2DestructionListener, b2DrawExtended)
from Box2D.Box2D import (b2Fixture, b2FixtureDef, b2Joint)
from Box2D.Box2D import (b2GetPointStates, b2QueryCallback, b2Random)
from Box2D.Box2D import (b2_addState, b2_dynamicBody, b2_epsilon, b2_persistState)


class fwDestructionListener(b2DestructionListener):
    """The destruction listener callback:
    "SayGoodbye" wordt aangeroepen als een verbinding of vorm is verwijdert.
    
    Args:
        b2DestructionListener ([class]): Verbindingen en vormen worden vernietigd wanneer 
        hun bijbehorende lichaam wordt vernietigd. Implementeer deze luisteraar zodat u 
        verwijzingen naar deze verbindingen en vormen teniet kunt doen.
        
    **Modifier**: 
        Daniël Boon   \n
    **Version**:
        1.12           \n
    **Date**:
        22-1-2020
    
    Warning:
        Deze code is geschreven door derden en waar nodig aangepast/vertaald door de projectgroep. 
        Dit is daarom niet volledig volgens Doxygen geformuleerd.

    """

    def __init__(self, test, **kwargs):
        """Hier wordt de klasse van fwDestructionListener geinitialiseerd.
        
        Args:
            test ([type]): [description]
        """
        super(fwDestructionListener, self).__init__(**kwargs)
        self.test = test


    def SayGoodbye(self, obj):
        """Verwijder een Box2D object.
        
        Args:
            obj: (@@@) Object die moet worden verwijderd uit de simulatie.
        """
        if isinstance(obj, b2Joint):
            if self.test.mouseJoint == obj:
                self.test.mouseJoint = None
            else:
                self.test.JointDestroyed(obj)
        elif isinstance(obj, b2Fixture):
            self.test.FixtureDestroyed(obj)

class fwQueryCallback(b2QueryCallback):
    """Klasse voor het aanmaken van Query callbacks
    
    Args:
        b2QueryCallback ([type]): [description]
    
    Returns:
        [type]: [description]

    **Modifier**: 
        Daniël Boon   \n
    **Version**:
        1.12           \n
    **Date**:
        22-1-2020  
    
    Warning:
        Deze code is geschreven door derden en waar nodig aangepast/vertaald door de projectgroep. 
        Dit is daarom niet volledig volgens Doxygen geformuleerd.

    """

    def __init__(self, p):
        """Initialisatie van de klasse fwQueryCallback.
        
        Args:
            p ([type]): [description]
        """
        super(fwQueryCallback, self).__init__()
        self.point = p
        self.fixture = None

    def ReportFixture(self, fixture):
        """Hier wordt gecontroleerd of er een nieuw object is aangemaakt.

        Args:
            fixture ([type]): [description]
        
        Returns:
            [type]: [description]
        """
        body = fixture.body
        if body.type == b2_dynamicBody:
            inside = fixture.TestPoint(self.point)
            if inside:
                self.fixture = fixture
                # We hebben het object gevonden, dus stop met vragen.
                return False
        # Ga door met vragen.
        return True


class Keys(object):
    """Deze functie wordt aangeroepen wanneer een andere functie een pointer genereerd, om nieuwe waardes te verversen.
    
    Args:
        object ([type]): [description]
    
    **Modifier**: 
        Daniël Boon   \n
    **Version**:
        1.12           \n
    **Date**:
        22-1-2020
    
    Warning:
        Deze code is geschreven door derden en waar nodig aangepast/vertaald door de projectgroep. 
        Dit is daarom niet volledig volgens Doxygen geformuleerd.

    """
    pass


class FrameworkBase(b2ContactListener):
    """De basis van het hoofd testbed geraamte.

    Als u van plan bent het testbed-framework te gebruiken en:
     * U wilt uw eigen renderer implementeren (anders dan Pygame, etc.):
       Leid hieruit je eigen klasse om je eigen testen te implementeren.
       Zie empty.py of een van de andere tests voor meer informatie.
     * Wilt u uw eigen renderer NIET implementeren:
       Leid je klasse uit Framework. De gekozen renderer in
       fwSettings (zie settings.py) of op de opdrachtregel wordt automatisch
       gebruikt voor uw test.

    **Modifier**: 
        Daniël Boon   \n
    **Version**:
        1.12          \n
    **Date**:
        22-1-2020   

    Warning:
        Deze code is geschreven door derden en waar nodig aangepast/vertaald door de projectgroep. 
        Dit is daarom niet volledig volgens Doxygen geformuleerd.
        
    """

    name = "None"
    description = None
    TEXTLINE_START = 30
    colors = {
        'mouse_point': b2Color(0, 1, 0),
        'bomb_center': b2Color(0, 0, 1.0),
        'bomb_line': b2Color(0, 1.0, 1.0),
        'joint_line': b2Color(0.8, 0.8, 0.8),
        'contact_add': b2Color(0.3, 0.95, 0.3),
        'contact_persist': b2Color(0.3, 0.3, 0.95),
        'contact_normal': b2Color(0.4, 0.9, 0.4),
    }

    def __reset(self):
        """Herstel alle variabelen naar hun start waardes.
        Niet aanroepen behalve bij initialisatie.
        """
        
        # Box2D-gerelateerd
        self.points = []
        self.world = None
        self.bomb = None
        self.mouseJoint = None
        self.settings = fwSettings
        self.bombSpawning = False
        self.bombSpawnPoint = None
        self.mouseWorld = None
        self.using_contacts = False
        self.stepCount = 0

        # Box2D-callbacks
        self.destructionListener = None
        self.renderer = None

    def __init__(self):
        """Initialisatie van de FrameworkBase klasse.
        """
        super(FrameworkBase, self).__init__()

        self.__reset()

        # Box2D Initialisatie
        self.world = b2World(gravity=(0, -10), doSleep=True)

        self.destructionListener = fwDestructionListener(test=self)
        self.world.destructionListener = self.destructionListener
        self.world.contactListener = self
        self.t_steps, self.t_draws = [], []
        self.fps = 0
        self.groundbody = 0
        self.settings.timeStep = 1 / 60
        self.settings.c_hz = 60

    def __del__(self):
        """Deze functie wordt aangeroepen wanneer een andere functie een pointer genereerd, om nieuwe waardes te verversen.
        """
        pass

    def Step(self, settings):
        """De belangrijkste stap voor de fysica.

        Zorgt voor de natuurkundige tekening (callbacks worden uitgevoerd na de world.Step() )
        en voor het tekeningen van aanvullende informatie.
        
        Args:
            settings (Class): instellingen van de simulatie. 
        """

        self.stepCount += 1
        # Doe niks als de settings HZ <= 0.
        if settings.hz > 0.0:
            timeStep = 1.0 / settings.hz
        else:
            timeStep = 0.0

        renderer = self.renderer

        # Als er is gepauzeerd, weergeef dat.
        if settings.pause:
            if settings.singleStep:
                settings.singleStep = False
            else:
                timeStep = 0.0

            self.Print("****GEPAUZEERD****", (200, 0, 0))

        # Zet de flags gebaseerd op wat de instellingen laten zien.
        if renderer:
            # convertVertices is alleen van toepassing als b2DrawExtended gebruikt wordt.  
            # Het geeft een indicatie dat de C code de box2d coördinaten moet omzetten naar beeld coördinaten.
            is_extended = isinstance(renderer, b2DrawExtended)
            renderer.flags = dict(drawShapes=settings.drawShapes,
                                  drawJoints=settings.drawJoints,
                                  drawAABBs=settings.drawAABBs,
                                  drawPairs=settings.drawPairs,
                                  drawCOMs=settings.drawCOMs,
                                  convertVertices=is_extended,
                                  )

        # Zet de andere instellingen die niet in de flags zitten.
        self.world.warmStarting = settings.enableWarmStarting
        self.world.continuousPhysics = settings.enableContinuous
        self.world.subStepping = settings.enableSubStepping

        # Herstel de punten voor collision.
        self.points = []

        # Vertel Box2D om te stappen.
        t_step = time()
        
        self.world.Step(self.settings.timeStep, settings.velocityIterations,
                        settings.positionIterations)

        self.world.ClearForces()
        t_step = time() - t_step

        # Update de debug teken instellingen zodat de hoekpunten op de juiste 
        # wijze omgezet worden naar beeld coördinaten
        t_draw = time()

        if renderer is not None:
            renderer.StartDraw()

        self.world.DrawDebugData()

        # Als de bom is bevroren, zorg dat deze verdwijnt.
        if self.bomb and not self.bomb.awake:
            self.world.DestroyBody(self.bomb)
            self.bomb = None

        # Zorg voor aanvullend tekeningen (fps, mouse joint, slingshot bomb,
        # contact points)

        if renderer:
            # Als er een mouse join is, teken dan de connectie tussen het object en de huidige pointer positie.
            if self.mouseJoint:
                p1 = renderer.to_screen(self.mouseJoint.anchorB)
                p2 = renderer.to_screen(self.mouseJoint.target)

                renderer.DrawPoint(p1, settings.pointSize,
                                   self.colors['mouse_point'])
                renderer.DrawPoint(p2, settings.pointSize,
                                   self.colors['mouse_point'])
                renderer.DrawSegment(p1, p2, self.colors['joint_line'])

            # Teken de slingshot bom.
            if self.bombSpawning:
                renderer.DrawPoint(renderer.to_screen(self.bombSpawnPoint),
                                   settings.pointSize, self.colors['bomb_center'])
                renderer.DrawSegment(renderer.to_screen(self.bombSpawnPoint),
                                     renderer.to_screen(self.mouseWorld),
                                     self.colors['bomb_line'])

            # Teken elk van de contact punten in verschillende kleuren.
            if self.settings.drawContactPoints:
                for point in self.points:
                    if point['state'] == b2_addState:
                        renderer.DrawPoint(renderer.to_screen(point['position']),
                                           settings.pointSize,
                                           self.colors['contact_add'])
                    elif point['state'] == b2_persistState:
                        renderer.DrawPoint(renderer.to_screen(point['position']),
                                           settings.pointSize,
                                           self.colors['contact_persist'])

            if settings.drawContactNormals:
                for point in self.points:
                    p1 = renderer.to_screen(point['position'])
                    p2 = renderer.axisScale * point['normal'] + p1
                    renderer.DrawSegment(p1, p2, self.colors['contact_normal'])

            renderer.EndDraw()
            t_draw = time() - t_draw

            t_draw = max(b2_epsilon, t_draw)
            t_step = max(b2_epsilon, t_step)

            try:
                self.t_draws.append(1.0 / t_draw)
            except:
                pass
            else:
                if len(self.t_draws) > 2:
                    self.t_draws.pop(0)

            try:
                self.t_steps.append(1.0 / t_step)
            except:
                pass
            else:
                if len(self.t_steps) > 2:
                    self.t_steps.pop(0)

            if settings.drawFPS:
                self.Print("Gecombineerde FPS %d" % self.fps)

            if settings.drawStats:
                self.Print("bodies=%d contacts=%d joints=%d proxies=%d" %
                           (self.world.bodyCount, self.world.contactCount,
                            self.world.jointCount, self.world.proxyCount))

                self.Print("hz %d vel/pos iterations %d/%d" %
                           (settings.hz, settings.velocityIterations,
                            settings.positionIterations))

                if self.t_draws and self.t_steps:
                    self.Print("Potential draw rate: %.2f fps Step rate: %.2f Hz"
                               "" % (sum(self.t_draws) / len(self.t_draws),
                                     sum(self.t_steps) / len(self.t_steps))
                               )

    
    # TODO: Dit is onbekend voor mij.   @@@
    def ShiftMouseDown(self, p):
        """Indicatie dat er een linker klik op punt p aanwezig was (wereld coördinaten) met de linker shift-toets ingedrukt.
        
        Args:
            p ([type]): [description]
        """
        self.mouseWorld = p

        if not self.mouseJoint:
            self.SpawnBomb(p)

    # TODO: Dit is onbekend voor mij.   @@@
    def MouseDown(self, p):
        """Indicatie dat er een linker klik op punt p aanwezig was (wereld coördinaten)
        
        Args:
            p ([type]): [description]
        """
        if self.mouseJoint is not None:
            return

        # Creeër en mouse joint op het geselecteerde lichaam (er van uit gaan dat het dynamisch is).
        # Maak een kleine doos.
        aabb = b2AABB(lowerBound=p - (0.001, 0.001),
                      upperBound=p + (0.001, 0.001))

        # Vraag de wereld voor overlappende figuren.
        query = fwQueryCallback(p)
        self.world.QueryAABB(query, aabb)

        if query.fixture:
            body = query.fixture.body
            # Een lichaam is geselecteerd. Creeër de mouse joint. 
            self.mouseJoint = self.world.CreateMouseJoint(
                bodyA=self.groundbody,
                bodyB=body,
                target=p,
                maxForce=1000.0 * body.mass)
            body.awake = True

    # TODO: Dit is onbekend voor mij.   @@@
    def MouseUp(self, p):
        """Linker muis knop omhoog.
        
        Args:
            p ([type]): [description]
        """
        if self.mouseJoint:
            self.world.DestroyJoint(self.mouseJoint)
            self.mouseJoint = None

        if self.bombSpawning:
            self.CompleteBombSpawn(p)

    # TODO: Dit is onbekend voor mij.   @@@
    def MouseMove(self, p):
        """Muis verschoven naar punt p, in wereld coördinaten.
        
        Args:
            p ([type]): [description]
        """
        self.mouseWorld = p
        if self.mouseJoint:
            self.mouseJoint.target = p

    # TODO: Dit is onbekend voor mij.   @@@

    def SpawnBomb(self, worldPt):
        """Begint de katapultbom door de beginpositie vast te leggen.
        Zodra de gebruiker de muis versleept en vervolgens loslaat
        zal CompleteBombSpawn worden opgeroepen en de werkelijke bom zal worden
        vrijgelaten.

        Args:
            worldPt ([type]): [description]
        """
        self.bombSpawnPoint = worldPt.copy()
        self.bombSpawning = True

    # TODO: Dit is onbekend voor mij.   @@@

    def CompleteBombSpawn(self, p):
        """Maak de katapultbom op basis van de twee punten
        (doorgegeven van de worldPt aan SpawnBomb naar p hier)

        Args:
            p ([type]): [description]
        """
        if not self.bombSpawning:
            return
        multiplier = 30.0
        vel = self.bombSpawnPoint - p
        vel *= multiplier
        self.LaunchBomb(self.bombSpawnPoint, vel)
        self.bombSpawning = False

    # TODO: Dit is onbekend voor mij.   @@@

    def LaunchBomb(self, position, velocity):
        """Een bom is een eenvoudige cirkel met de opgegeven positie en snelheid.
        Positie en snelheid moeten b2Vec2's zijn.

        Args:
            position ([type]): [description]
            velocity ([type]): [description]
        """
        if self.bomb:
            self.world.DestroyBody(self.bomb)
            self.bomb = None

        self.bomb = self.world.CreateDynamicBody(
            allowSleep=True,
            position=position,
            linearVelocity=velocity,
            fixtures=b2FixtureDef(
                shape=b2CircleShape(radius=0.3),
                density=20,
                restitution=0.1)

        )

    # TODO: Dit is onbekend voor mij.   @@@

    def LaunchRandomBomb(self):
        """Creëer een nieuwe bom en lanceer deze op het testbed.
        
        """
        p = b2Vec2(b2Random(-15.0, 15.0), 30.0)
        v = -5.0 * p
        self.LaunchBomb(p, v)

    def SimulationLoop(self):
        """De hoofd simulatie loop. Niet overschrijven, maar vervang Step in plaats daarvan.
        """ 

        # Reset the text line to start the text from the top
        self.textLine = self.TEXTLINE_START

        # Draw the name of the test running
        self.Print(self.name, (127, 127, 255))

        if self.description:
            # Draw the name of the test running
            for s in self.description.split('\n'):
                self.Print(s, (127, 255, 127))

        # Do the main physics step
        self.Step(self.settings)

    def ConvertScreenToWorld(self, x, y):
        """Geeft een b2Vec2 terug in wereld coördinaten van het doorgegeven scherm.

        Args:
            x (int): x cordinaat.
            y (int): y cordinaat.
        
        Raises:
            NotImplementedError: Error dat het nog niet is aangemaakt.
        """
        raise NotImplementedError()

    def DrawStringAt(self, x, y, str, color=(229, 153, 153, 255)):
        """Teken een string van tekst naar het scherm op de x,y coördinaten.
        NOTE: Renderer subklasses moeten dit implementeren.
        
        Args:
            x ([type]): [description]
            y ([type]): [description]
            str ([type]): [description]
            color (tuple, optional): [description]. Defaults to (229, 153, 153, 255).
        
        Raises:
            NotImplementedError: [description]
        """
        raise NotImplementedError()

    def Print(self, str, color=(229, 153, 153, 255)):
        """Teken wat tekst op de bovenste statusregels
         en ga door naar de volgende regel.
        NOTE: Renderer subklasses moeten dit implementeren. 
        
        Args:
            str ([type]): [description]
            color (tuple, optional): [description]. Defaults to (229, 153, 153, 255).
        
        Raises:
            NotImplementedError: [description]
        """
        raise NotImplementedError()

    def PreSolve(self, contact, old_manifold):
        """Dit is een kritieke functie wanneer er veel contacten zijn in de wereld.
        Deze moet zoveel mogelijk geoptimaliseerd worden.
        
        Args:
            contact ([type]): [description]
            old_manifold ([type]): [description]
        """
        if not (self.settings.drawContactPoints or
                self.settings.drawContactNormals or self.using_contacts):
            return
        elif len(self.points) > self.settings.maxContactPoints:
            return

        manifold = contact.manifold
        if manifold.pointCount == 0:
            return

        state1, state2 = b2GetPointStates(old_manifold, manifold)
        if not state2:
            return

        worldManifold = contact.worldManifold

        # TODO: find some way to speed all of this up.
        self.points.extend([dict(fixtureA=contact.fixtureA,
                                 fixtureB=contact.fixtureB,
                                 position=worldManifold.points[i],
                                 normal=worldManifold.normal.copy(),
                                 state=state2[i],
                                 )
                            for i, point in enumerate(state2)])
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

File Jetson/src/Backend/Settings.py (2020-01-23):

"""
    Instellingen voor Box2D en Pygame. 

    File:
        Settings.py
    Date:
        21-1-2020
    Version:
        V1.01
    Modifier:
        Daniël Boon    
    Used_IDE:
        Visual Studio Code (Python 3.6.7 64-bit)
    Version management:
        1.0:
            Verwijzingen naar bestandsnamen gewijzigd
                Header toegevoegd
        1.01:
            Spelling en grammatica commentaren nagekeken.
            Engels vertaald naar Nederlands.
"""

#!/usr/bin/env python
# -*- coding: utf-8 -*-
#
# C++ version Copyright (c) 2006-2007 Erin Catto http://www.box2d.org
# Python version by Ken Lauer / sirkne at gmail dot com
#
# Implemented using the pybox2d SWIG interface for Box2D (pybox2d.googlecode.com)
#
# This software is provided 'as-is', without any express or implied
# warranty.  In no event will the authors be held liable for any damages
# arising from the use of this software.
# Permission is granted to anyone to use this software for any purpose,
# including commercial applications, and to alter it and redistribute it
# freely, subject to the following restrictions:
# 1. The origin of this software must not be misrepresented; you must not
# claim that you wrote the original software. If you use this software
# in a product, an acknowledgment in the product documentation would be
# appreciated but is not required.
# 2. Altered source versions must be plainly marked as such, and must not be
# misrepresented as being the original software.
# 3. This notice may not be removed or altered from any source distribution.


class fwSettings(object):
    # De standaard backend om te gebruiken (can be: pyglet, pygame, etc.)
    backend = 'pygame'

    # Fysica opties
    hz = 60.0
    velocityIterations = 8
    positionIterations = 3
    # Maakt natuurkundige resultaten meer nauwkeurig (zie Box2D wiki).
    enableWarmStarting = True
    enableContinuous = True     # Berekend de tijd van impact.
    enableSubStepping = False

    # Tekenen
    drawStats = True
    drawShapes = True
    drawJoints = True
    drawCoreShapes = False
    drawAABBs = False
    drawOBBs = False
    drawPairs = False
    drawContactPoints = False
    maxContactPoints = 100
    drawContactNormals = False
    drawFPS = True
    drawMenu = True             # Verander door op F1 te drukken
    drawCOMs = False            # Middenpunt van de massa
    pointSize = 2.5             # Pixel radius voor de tekenpunten

    # Verschillende testbed opties.
    pause = False
    singleStep = False
    # Draai de initialisatie tests zonder graphische middelen en stop daarna (voor testdoeleinden)
    onlyInit = False

#             tekst                  variabele
checkboxes = (("Warm Starting", "enableWarmStarting"),
              ("Time of Impact", "enableContinuous"),
              ("Sub-Stepping", "enableSubStepping"),
              ("Draw", None),
              ("Shapes", "drawShapes"),
              ("Joints", "drawJoints"),
              ("AABBs", "drawAABBs"),
              ("Pairs", "drawPairs"),
              ("Contact Points", "drawContactPoints"),
              ("Contact Normals", "drawContactNormals"),
              ("Center of Masses", "drawCOMs"),
              ("Statistics", "drawStats"),
              ("FPS", "drawFPS"),
              ("Control", None),
              ("Pause", "pause"),
              ("Single Step", "singleStep"))

sliders = [
    {'name': 'hz', 'text': 'Hertz', 'min': 5, 'max': 200},
    {'name': 'positionIterations', 'text': 'Pos Iters', 'min': 0, 'max': 100},
    {'name': 'velocityIterations', 'text': 'Vel Iters', 'min': 1, 'max': 500},
]

from optparse import OptionParser

parser = OptionParser()
list_options = [i for i in dir(fwSettings)
                if not i.startswith('_')]

for opt_name in list_options:
    value = getattr(fwSettings, opt_name)
    if isinstance(value, bool):
        if value:
            parser.add_option('', '--no-' + opt_name, dest=opt_name,
                              default=value, action='store_' + str(not value).lower(),
                              help="don't " + opt_name)
        else:
            parser.add_option('', '--' + opt_name, dest=opt_name, default=value,
                              action='store_' + str(not value).lower(),
                              help=opt_name)

    else:
        if isinstance(value, int):
            opttype = 'int'
        elif isinstance(value, float):
            opttype = 'float'
        else:
            opttype = 'string'
        parser.add_option('', '--' + opt_name, dest=opt_name, default=value,
                          type=opttype,
                          help='sets the %s option' % (opt_name,))


fwSettings, args = parser.parse_args()

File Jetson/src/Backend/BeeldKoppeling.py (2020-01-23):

"""
    Omschrijving: Koppelt de beeldherkenning aan de simulatie. Vertaalt hierbij de bal coördinaten in pixel positie
    van de beeldherkenning naar coördinaten voor de simulatie. 

    Wanneer debug_flag=True zal de bal bestuurd kunnen worden d.m.v. trackbars. Wanneer deze True is zal een vooraf gedefinieerde
    video worden afgespeeld.

    File:
        BeeldKoppeling.py
    Date:
        20-1-2020
    Version:
        1.12
    Modifier:
        Kelvin Sweere
    Used_IDE:
        Visual Studio Code (Python 3.6.7 64-bit)
    Schematic:
        Lucidchart: NLE/AI/Bal update met beeldherkenning
    Version management:
        1.0:
            Release Jetson Nano.
        1.10:
            Functies met underscore gemaakt ipv C++ lowerCamelCase style.
        1.11:
            Doxygen documentatie toegevoegd.
            Spelling verbeterd.
        1.12:
            Spelling en grammatica commentaren nagekeken
"""

import cv2

class BeeldKoppeling():
    """Klasse die een koppeling maakt tussen de beeldherkenning en de simulatie. Vertaalt hierbij de bal coördinaten in pixel positie
    van de beeldherkenning naar coördinaten voor de simulatie. 

    **Author**: 
        Kelvin Sweere \n
    **Version**:
        1.12           \n
    **Date**:
        20-1-2020
    """
    def __init__(self, debug_flag=False):
        """        
        Args:
            debug_flag: (bool, optional) keuze of er trackbars worden gestart die de bal besturen. Default is False.
        """
        # Coördinaten van de bal (in verhouding).
        self.x_s = None     # X coördinaat simulatie
        self.y_s = None     # Y coördinaat simulaite

        self.x_p = None     # X coördinaat simulatie
        self.y_p = None     # Y coördinaat simulatie
        
        # Settings van de img. Worden ook opgehaald door get_ball().
        self.WIDTH_IMG = None
        self.HEIGHT_IMG = None
        self.DEBUG_FLAG = debug_flag    # Flag waarbij gekozen kan worden of trackbars worden toegevoegd.

        if self.DEBUG_FLAG:
            self._init_trackbars()   # Debug versie! Command wanneer de debug niet gebruikt wordt!
        else:
            # TODO: verwijderen wanneer niet meer gebruikt!:
            from glob import glob
            import os
            self.files = glob("C:\\Users\\" + os.getlogin() + "\\Stichting Hogeschool Utrecht\\NLE - Documenten\\Test foto's\\V1.3 cam normal Wide angle + ball\\output_fast.avi")
            # Files is een bestand met daarin de video. Dit is voor demonstartie doeleinde.
            self._init_video_function()

    def get_pos_vision(self):
        """Voert de gehele pipeline in een keer uit. Haalt de gegevens op van trackbars en geeft hiervan de coördinaten van de simulatie terug.
        
        Returns:
            (tuple) x & y coördinaten van de simulatie van de bal.
        """
        # TODO: terugzetten wanneer niet meer gebruikt!
        # self.get_ball()
        self.test_video_function()
        # ! -------------------------------------------
        self._convert_2_sim_cor()  # Converteren beeld pix -> sim pix
        return (self.x_s, self.y_s) # Geeft de simulatie coördinaten terug.


    def _init_trackbars(self):
        """initialiseer debug trackbars.
        """
        def nothing(x): # Dummy functie voor cv2.createTrackbar.
            pass

        cv2.namedWindow('Cordinates')   # Maakt een window aan.
        self.MAX_TRACKBAR_VAL = 100
        # Maakt trackbars aan voor het verander van de kleur/
        cv2.createTrackbar('X','Cordinates',0,self.MAX_TRACKBAR_VAL,nothing)
        cv2.createTrackbar('Y','Cordinates',0,self.MAX_TRACKBAR_VAL,nothing)
        
        # Zet de trackbars op 50%
        cv2.setTrackbarPos('X',"Cordinates", int(self.MAX_TRACKBAR_VAL/2))
        cv2.setTrackbarPos('Y',"Cordinates", int(self.MAX_TRACKBAR_VAL/2))


    def map_function(self, val, in_min, in_max, out_min, out_max):
        """Map functie (zoals in de Arduino IDE) die de input in een vaste verhouding verschaalt naar de output.
        
        Args:
            val: (int) waarde die geschaald moet worden.
            in_min: (int) minimale waarde die de input kan hebben.
            in_max: (int) maximale waarde die de input kan hebben.
            out_min: (int) minimale waarde die de output mag krijgen.
            out_max: (int) maximale waarde die de output mag krijgen.
        
        Returns:
            (int) geschaalde waarde van de input.
        """
        return (val - in_min) * (out_max - out_min) / (in_max - in_min) + out_min;


    def _convert_2_sim_cor(self):
        """Zet de pixel positie van de beeldherkenning om naar een x & y positie voor de simulatie.
        """
        # x_simulatie posite
        self.x_s = self.map_function(self.x_p, 0, self.WIDTH_IMG, -19.35, 19.35)
        self.y_s = self.map_function(self.y_p, 0, self.HEIGHT_IMG, 17.42, 0)
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

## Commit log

2020-01-13 Jetson files in eigen map gezet
2020-01-16 Added FindContours and replaced Raster with Extra in Backend
    [Extra.py]
2020-01-16 _initAISettings() toegevoegd voor de parameters van de AI in de init.
2020-01-16 Headers aangepast aan de nieuwe stijl.
2020-01-20 In FoosTronics.run() check if pygame.running is True, else release camera.
2020-01-20 changes on Jetson Nano
2020-01-20 Ophalen afbeeldingen van media of camera tot bal detection via een Thread
2020-01-21 go_home functie operationeel zonder hardware sensor voor home positie
2020-01-21 Keeper_sim op het midden gezet.
2020-01-21 Ophalen van afbleedingen van media of camera tot bal detectie via een thread.
2020-01-21 fixing shooting simulation + go home validation
    [PygameFramework.py, USB.py]
2020-01-21 wanneer shoot_bool is False wordt de camera gebruikt.
2020-01-21 mogelijke fix toegevoegd voor blocked niet kunnen registreren
    [DeepQLearning.py]
2020-01-22 Aanpassingen op Jetson Nano voor demo.
2020-01-23 set boolean values for jetson nano
2020-01-23 nieuwe feature ball wordt niet meer weergegeven in simulatie waneer uit het veld + fixed error wanneer geen gyroscope is aangesloten
    [PygameFramework.py]
2020-01-23 Optie eerst trackbars toevoegen dan simulatie starten. En try except toegevoegd voor de import van de mpu6050.
2020-01-23 overbodige print eruit gehaald + fixed controller error zonder drivers
    [USB.py]
2020-01-23 Controller in een Thread
2020-01-23 Doxygen commentaar tabel fix.
    [DeepQLearning.py]
2020-01-23 Controller que wordt gevult in main.py
2020-01-23 in main.py check of de Controller que vol is
2020-01-23 Extra files toegevoegd.
    [AssemblyHendelGyro.SLDASM, Assembly_hendel+gyro.SLDASM, CamCaseBottom.SLDPRT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]
